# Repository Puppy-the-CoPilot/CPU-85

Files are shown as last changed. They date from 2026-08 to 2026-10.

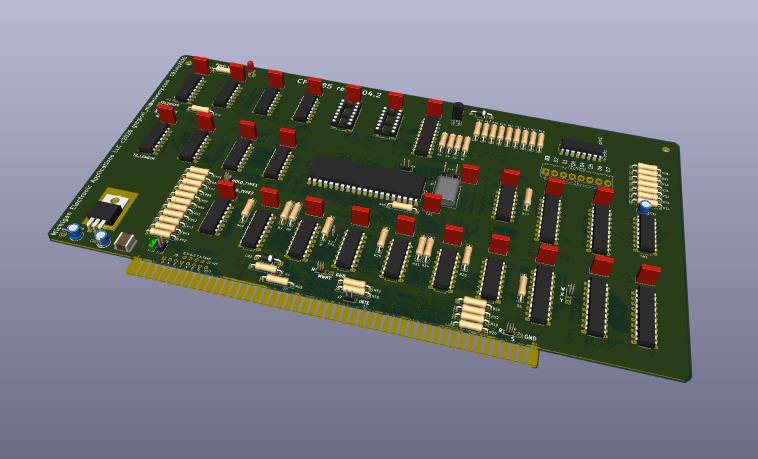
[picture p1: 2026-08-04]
CPU-85_R104_KiCAD_3D_View_21July2026.JPG

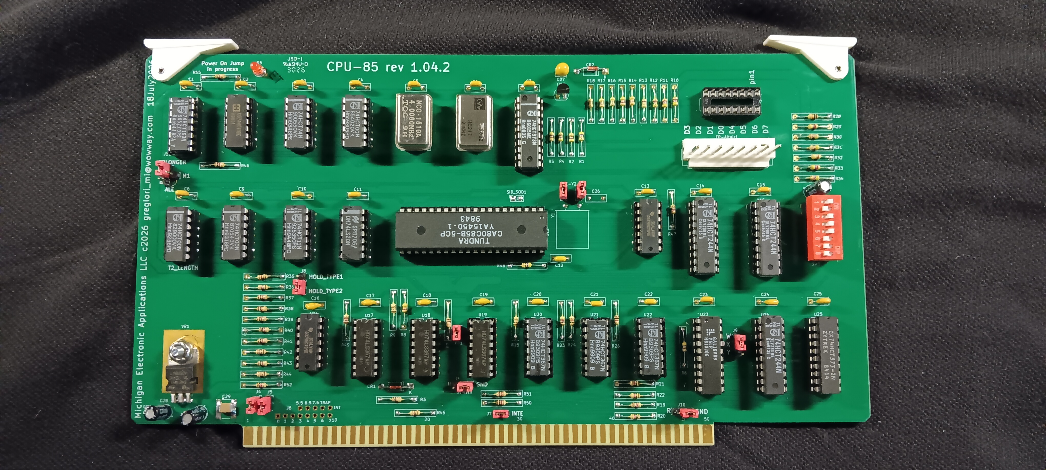
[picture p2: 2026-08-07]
photo_CPU85_front_6Aug2026_1000012285.jpg

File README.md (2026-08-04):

# CPU-85
8085 CPU based 1970s to 1980s era S-100 IEEE696 board outline card
last update: 28 July 2026

Purpose:
     * update MITS/Altair CPU-A board for modern EMC PCB layout principles
              ** have more Vcc and Ground to avoid switching niose risk
                    *** this helps prevent self induced switching noise (Conducted Immunity)
                    *** helps prevent Radiated Emissions in AM Band
              ** place decopupling capacitors next their respective ICs
     * improve CPU speed above 1975 limitations of the early 8080A as implemented by MITS/Altair/IMSAI
              ** HMOS 8085A upto 6MHz 
              ** CMOS 80C85A upto 5MHz, lower power
              ** CMOS CA80C85B upto 8MHz, B indicates a silicon die revision
     * add low voltage or 5Vcc < 4.7V forced RESET to help power up reliability
     * support IMSAI 8080A Front Panel and MITS/Altair 8800 Front Panel
              ** have 2 ribbon cable connectors
              ** S-100 jumpers and circuits for supporting signal varations
     * add Power On Jump to a user defined address (1K increments)
     * minimalist hardware, no IO, no RAM, no ROM, etc... just CPU
     * allow easy changing of CPU MHz speed 
              ** use DIP oscillator as flexible source
              ** have PCB holes to allow HC case quartz crystal
              ** allow use of 8 or 14 pin DIP oscillators
     * use jumper blocks to support IMSAI and MIS/Altair variations (they are not 100% the same)
     * maybe design a spin off varation to use the NSC800 (a Z80A hybrid with 8085 like pin out)
     * avoid using 8212 latch and 8216 bidirectional drivers (availability issues + old plastic encapsulation manufacturing)
  
Schematic: Completed 10 July 2026
           filename=CPU-85_schematic_21July2026.pdf
           (a living document, I will add more notes and validation results as those become available)

Software:  what ever the user had to run IMSAI 8080 or MITS/Altair 8800
           (this board lacks dedicated I/O so no special I/O drivers are needed)

PLD or PLA:  Yes there is 1, U23 is a GAL16V8 used as a CPU State Decoder
             filename=CPU-85_U23.jed

PCB Layout:  Gerbers Completed 17 July 2026
             filename=CPU-85_r104-F_Silkscreen.gbr

Bill Of Material:  Completed 18 July 2026
                   filename=CPU-85_rev1dot04_BOM_18July2026.xls

PCB Status: first blank check samples are being made in July 2026

First Validation Sample: In Progress as of 4 August 2026

Planned Validation:
     * test in IMSAI non Front Panel IMSAI PCS 80/30 
     * test in IMSAI 8080 system with IMSAI Front Panel 8080A
     * test in MITS/Altair 8800 system with MITS/Altair Front Panel

Errata:  None Known

contact email:  greglori_mi@wowway.com

Answers to Questions people asked:

Q:  8080A S-100 Boards had unique circuits for using their Front Panels
A:  I compared the schematics of IMSAI 8080A MPU-A, IMSAI 8085A MPU-B, and MITS/ALTAIR 8080 CPU-A.
    On IMSAI MPU-B, they just ran out of time and physical PCB space for the needed circuits... or just gave up on trying to achieve Front Panel compatibility.
    This board has different circuits to choose from in places where IMSAI, Intel, IEEE696, and MITS/Altair had some different circuits or logic.
    Most logic circuits were the same between IMSAI and MITS/Altair boards, but a few were differences... thus jumper blocks are used for circuit selections.
    So yes, there is some extra circuitry on this panel.
    See Page 12 of the schematic.  

Q: 8080A had a quirk or mirroring A0-A7 on A8-A15 during IO operations, does this panel do that?
A: Yes, the 8085A does this itself already.  Intel copied this characteristic from the 8080A to the 8085A.
   The OKI80C85A and CA80C85B specifications do not mention the IO address mirroring (they do state 100% pin and signal compatible).
   When A8-A15 are TriState, there are 5V pull ups to make FFH as a default for the Front Panel.

Q: One person wrote this panel uses 74HCTxx logic gates, they had mixed results using 74HCT family gates...
A: Lately I've been using 74HCT on my designs for lower power consumption.   
   For me, 74LS and 74HCT have been interchangeable for CPU speed <5MHz, I've had no bad experiences.
   Only difference I found was on 74HCT07 is clamped to Vcc or 5V, where as 74LS07 is true Open Collector with Vce=30V (no connection to Vcc)... 
   74HC07/74HCT07 and 7407/74LS07 are not interchangeable when pull up voltage is >5V.

Q. a person made a program to use 8085's RIM and SIM instructions...can SID and SOD be used?
A. Yes, SID and SOD are brought out from CPU to solder holes and pads. 

Q. Hard Gold on S-100 Edge Card fingers?
A. Yes, although Gold is now very expensive, 20u" (Industrial grade) is used for durabiliity vs. 30u" (Medical/Military grade)

Q. Hot Air Solder Pre Tin solder pads
A. No.  To prevent any surface oxidation before parts get soldered and to allow for a long shelft life, a thin 3u" gold coating has been applied

Q. NCS800 CPU version?
A. Probably not to be designed or made.  There is no interest, there are already Z80 CPU panels with IMSAI Front Panel ribbon connectors
   that go faster than the NSC800.  NCS800 offers no speed or any other improvement over the existing Z80 PCBs.  
   The NSC800 was not developed further as a product, only a 4MHz version appears to exist.

Q. M1 OpCode Fetch and other CPU State info on the S-100 Data Out Bus during PSYNC was missing...
A. Added as a result of an early July Vintage Computer Group schematic review (hence the July 10 reivsion);
   the CPU States are now latched and placed on the S-100 DO0-DO7 signals during the PSYNC Cycle.
   On the 8080A, the PSYNC cycle lasted 4 XTAL clock cycles, or 2T machine states; on this panel
   the user can select PSYNC to be 1 of 3 sources: sM1, ALE as used by IMSAI MPU-B (1T 8085A machine cycle), or a 
   lengthened 8080A like signal (2T cycles long).

Q. what is done with extended address A16 to A23?
A. just like 1975 and 1970 era CPU panels, the pre IEEE-696 S-100 pins for A16-A23 are left floating, no pull ups or pull downs on this panel;
   if the receiving S-100 system has bus card termination, they will be pulled up to about 2.3V to 2.5V or logic 1 by the signal line terminators;
   this panel can only address 64K bytes like the original 1970s era CPU panels

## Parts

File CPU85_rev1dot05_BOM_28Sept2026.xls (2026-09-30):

BILL OF MATERIALS |  | CPU-85 BOARD rev 1.04.2 and 1.05
original draft, 18 July 2026
6August2026 update
7August2026 update
11August2026, added column M and N cost estimates
16Aug2026, added note about avoiding 85C85A;, 80C85AH is OK
28Aug2025 U10 and U27 updates
28Sept2026 U1 changed, U23 file updated, C27 no longer needed
Reference Label(s) | Qty | Value | Data Sheet | Footprint |  | Est cost | Possible Purchase web pages |  | (these are examples, no one source has everything, I bought from different sites)
procedure info | AR | 24-7068-1401 Kester Sn 96.5% Ag 3% Cu 0.5% 0.020inch diameter No Clean Flux Solder (RoHS compliant, OK to send a finished board to Europe) ANSI-STD-006B or equivalent |  |  |  | $0.00 | you might already have this
procedure info | info | NOTE: I find small diameter solder is easier to apply. Too easy to melt and apply excessive solder with larger diameter solder. |  |  |  | NA
procedure info | alternative | 24-6337-9702 Kester Sn 60% Pb 40% 0.015inch diameter Flux Core Solder (not RoHS compliant, OK for USA only) ANSI-STD-004 or equivalent (from Mouser.com) |  |  |  | $0.00 | you might already have this
procedure info | optional | black vinyl electrical tape 3M, UtiliTech |  |  |  | $0.00 | you might already have this
procedure info | AR | Kwik Clean Flux Cleaner 16 Oz (available from Amazon), might need 2 bottles if rosin core solder is used |  |  |  | $0.00 | you might already have this
procedure info | info | Do not use >70% Isopropyl Alcohol = too harsh, it turns any surface contaminants to an adhesive like goo that is difficult to remove and the result looks terrible. |  |  |  | NA
procedure info | AR | ZEP Heavy Duty Citrus Degreaser (24oz squirt bottle) |  |  |  | $0.00 | you might already have this
procedure info | AR | Distilled Water for rinse off |  |  |  | $0.00 | I used tap water
J1, rev 1.04,2 | obsolete | blank CPU-85 PCB panel, 2 layer, FR4, IEEE696 size, 30U” hard gold edge connector |  | s100_panel:S-100-IEEE696_ejector_holes_3July2026 |  | NA | need to get 2 or 3 quotes, I don’t know cost yet, wide cost variation for quantity = 5, 25, 50
J1, rev 1.04,3 (with inner Vcc and Ground planes) | none made | blank CPU-85 PCB panel, 4 layer, FR4, IEEE696 size, 30U” hard gold edge connector |  | s100_panel:S-100-IEEE696_ejector_holes_3July2026 |  | NA
J1, rev 1.05 (has 1.04.2 silk screen corrections) | not yet made | blank CPU-85 PCB panel, 2 layer, FR4, IEEE696 size, 15U” hard gold edge connector |  | s100_panel:S-100-IEEE696_ejector_holes_3July2026 |  | NA
schematic | document | 1.04.2 and 1.05 CPU-85 schematic, instructions, user options, design info | CPU-85_schematic_17July2026.pdf will have newer text updates |  |  | NA
C1,C2,C3,C4,C5,C6,C7,C8,C9,C10,C11,C12,C13,C14,C15,C16,C17,C18,C19,C20,C21,C22,C23,C24,C25 | 25 | 100nf, 50V, dipped MLCC leaded, ceramic | K104M15X7RF5TL2 | Capacitor_THT:C_Rect_L7.2mm_W2.5mm_P5.00mm_FKS2_FKP2_MKS2_MKP2 |  | $10.00 | eBay purchase | https://www.ebay.com/itm/137189394879?_skw=100nf+50V+MLCC+radial&itmmeta=01KZRSP62M9DDHPF0N0Z78RN4S
C26 | optional | 20pf, 25V (use only with Y1 <4MHz) | K104M15X7RF5TL2 | Capacitor_THT:C_Rect_L7.2mm_W2.5mm_P5.00mm_FKS2_FKP2_MKS2_MKP2 |  | $0.00
C27 | not required | 10nF to 10uF 10V to 50V ceramic for low leakage, C27 not needed U27 provides >300mS reset time | CGA5L1X7R1C106K160AC | Capacitor_THT:C_Disc_D3.8mm_W2.6mm_P2.50mm |  | $0.79 | https://www.jameco.com/z/TM10-16-James-Electronics-10-uF-16-Volt-Tantalum-Capacitor_94060.html
C28,C30,C31 | 3 | 10uF 50V, radial electrolytic (25V minimum) |  | Capacitor_THT:CP_Radial_D5.0mm_P2.50mm |  | $0.45 | https://www.jameco.com/z/ECA-1HM100-JVP-Jameco-ValuePro-10-uF-50-Volt-Radial-Capacitor_29891.html
C29 | 1 | 10uf, 25V, 1812 size ceramic or SMC tantalum (to insure low ESR) | 2388-PCT47/16CK | Capacitor_SMD:C_2225_5664Metric_Pad1.80x6.60mm_HandSolder |  | $0.25 | almost any SMD 1210 to 1825 will fit on the pads. Mine was from a scrap Smd machine strip
CR1 | optional | 1N4148, or 1N914, with C27 deleted, this diode is no longer needed to discharge C27
CR2 | 1 | 1N4148, or 1N914, current is less than 50mA (small signal) | http://www.vishay.com/docs/88525/1n5817.pdf | Diode_THT:D_DO-41_SOD81_P10.16mm_Horizontal |  | $0.06 | https://www.jameco.com/z/1N4148-Fairchild-onsemi-Diode-1N4148-100V-200mA-10mA-If-Small-Signal-Switching-Bulk-_36038.html
D5 | 1 | T1 LED (shows when PCB is in POJ, any color is OK, I used a red LED) |  | LED_THT:LED_D3.0mm |  | $0.09 | https://www.jameco.com/z/L-354HD-MCD-Electronics-Red-LED-Diffused-3mm-T1-2-8V-695nm-2-5mcd_2329183.html
FP-Altair1 | option | Molex 26-60-4080 VERT 8POS 3.96MM (for MITS/Altair Front Panel) |  | Connector_Molex:Molex_KK-396_A-41791-0008_1x08_P3.96mm_Vertical | I can sell with PCB | $1.10 | eBay purchase | https://www.ebay.com/itm/134631814875
 |  | Implementation varaition1: use wire cutters, break off female retention clip and keep the white plastic connector base (no retaining feature is most common)(cracks off easily) |  |  |  | NA
 |  | Implementation varaition2: use pliers, pull out all pins from the white connector, no plastic connector base (just use the big pins) |  |  |  | NA
 |  | Implementation varaition3: solder wires to Front Panel directly into the PCB, don’t use a connector (not recommended) |  |  |  | NA
 |  | Implementation varaition4: use mating 10 pin female connector (2 cavities are empty, yes its too wide, 8 position female connector does exist) |  |  |  | NA
 |  | Implementation varaition5: solder it in, keep the female connector retaining clip |  |  |  | NA
 |  | NOTE: Due to connector height, CPU card must be on the end of mother panel or adjacent S-100 must have no card installed to allow for mating connector and wires) |  |  |  | NA
FP-IMSAI1 | option | 16pin DIP socket (to IMSAI Front Panel) |  | Package_DIP:DIP-16_W7.62mm_LongPads |  | $0.00 | https://www.jameco.com/z/1-2199298-4-TE-Connectivity-16-Position-Dual-Wipe-Ladder-Style-DIP-IC-Socket-0-3-Wide-0-1-Pitch_2246080.html
R1,R2,R4,R5,R6,R48 | 6 | 470, 5% tol, 1/6W used, 5% tol, 1/8W or 1/10W, 1977 original was 1/4W |  | s100_panel:R_Axial_DIN0309_L7.5mm_D2.7mm_P12.50mm_Horizontal |  | $0.09 | eBay purchase | https://www.ebay.com/itm/406736220263?_skw=1%2F8w+resistor&itmmeta=01KZRSD28YGP9NY7HF8VVWRQE5&var=676974156631
R3,R9,R14,R19,R20,R21,R22,R23,R24,R25,R26,R35,R36,R37,R39, R40,R41,R42,R43,R44,R45,R46,R47,R49,R50,R51,R52,R55 | 28 | 1K, 5% tol, 1/6W used, 5% tol, 1/8W or 1/10W, 1977 original was 1/4W |  | s100_panel:R_Axial_DIN0309_L7.5mm_D2.7mm_P12.50mm_Horizontal |  | $0.42 | eBay purchase | https://www.ebay.com/itm/406736220263?_skw=1%2F8w+resistor&itmmeta=01KZRSD28YGP9NY7HF8VVWRQE5&var=676974156631
R7,R28,R38 | 3 | 10K, 5% tol, 1/6W used, 5% tol, 1/8W or 1/10W, 1977 original was 1/4W |  | s100_panel:R_Axial_DIN0309_L7.5mm_D2.7mm_P12.50mm_Horizontal |  | $0.04 | eBay purchase | https://www.ebay.com/itm/406736220263?_skw=1%2F8w+resistor&itmmeta=01KZRSD28YGP9NY7HF8VVWRQE5&var=676974156631
R8,R10,R11,R12,R13,R15,R16,R17,R18,R29,R30,R31,R32,R33,R34 | 15 | 4.7K, 5% tol, 1/6W used, 5% tol, 1/8W or 1/10W, 1977 original was 1/4W |  | s100_panel:R_Axial_DIN0309_L7.5mm_D2.7mm_P12.50mm_Horizontal |  | $0.22 | eBay purchase | https://www.ebay.com/itm/406736220263?_skw=1%2F8w+resistor&itmmeta=01KZRSD28YGP9NY7HF8VVWRQE5&var=676974156631
no label | optional | 8pin DIP sockets, dual wipe, for 8 pin oscillators (remove or push out from the bottom pins 2,3,6,7 for Y2 and Y3 oscillators) |  |  |  | $0.00 | https://www.jameco.com/z/390261-2-TE-Connectivity-8-Position-Dual-Wipe-Ladder-Style-DIP-IC-Socket-0-3-Wide-0-1-Pitch_526299.html
no label | 11 | 14pin DIP sockets, dual wipe (on 2 sockets remove or push out from the bottom pins 2,3,5,6,9,10,12,13 for 8 and 14 pin Y2 and Y3 oscillators) |  |  |  | $2.42 | https://www.jameco.com/z/ICS-314-T-Jameco-ValuePro-Socket-IC-14-Pin-Dual-Wipe-Low-Profile-0-3-Inch-Wide_112214.html
no label | 9 | 16pin DIP sockets, dual wipe |  |  |  | $1.62 | https://www.jameco.com/z/ICS-316-T-Jameco-ValuePro-IC-Socket-16-Pin-Dual-Wipe-Low-Profile-0-3-Inch-Wide_112222.html
no label | 6 | 20pin DIP sockets, dual wipe |  |  |  | $1.14 | https://www.jameco.com/z/20LPD-Jameco-ValuePro-20-Pin-0-3-Inch-Wide-Low-Profile-Dual-Wipe-IC-Socket_112248.html
no label | 1 | 40pin DIP socket, dual wipe |  |  |  | $0.59 | https://www.jameco.com/z/ICS-640-T-Jameco-ValuePro-40-Pin-Dual-Wipe-Low-Profile-IC-Socket-0-60-Inch-Wide_112311.html
U1 | 1 | 74HCT161, 4 bit counter with asynchronous reset | http://www.ti.com/lit/gpn/sn74LS161 | Package_DIP:DIP-16_W7.62mm_LongPads |  | $1.05
U2 | 1 | 74HCT02 | http://www.ti.com/lit/gpn/sn74hct02 | Package_DIP:DIP-14_W7.62mm_LongPads |  | $2.75 | eBay purchase | https://www.ebay.com/itm/163652946861?_skw=74HCT02+DIP&itmmeta=01KZRV2DQ9684WWSCPAVSTCC3Z
U3 | 1 | 74HCT74 | https://assets.nexperia.com/documents/data-sheet/74HC_HCT74.pdf | Package_DIP:DIP-14_W7.62mm_LongPads |  | $0.69 | https://www.jameco.com/z/74HCT74-Major-Brands-IC-74HCT74-DUAL-D-TYPE-FLIP-FLOP_45137.html
U4,U8,U9 | 3 | 74HCT00 | http://www.ti.com/lit/gpn/sn74hct00 | Package_DIP:DIP-14_W7.62mm_LongPads |  | $2.67 | https://www.jameco.com/z/74HCT00-Major-Brands-IC-74HCT00-QUAD-2-INPUT-POSITIVE-NAND-GATE_44871.html?CID=MERCH
U7, U25 | 2 | 74HCT373 alternative is 74LS373 | http://www.ti.com/lit/gpn/sn74LS373 | Package_DIP:DIP-20_W7.62mm_LongPads |  | $0.90 | https://www.jameco.com/z/74HCT373-On-Semiconductor-IC-74HCT373-OCTAL-D-TYPE-FLIP-FLOP-TRANSPARENT-LATCH_45065.html
U10 | 1 | 74HCT10 |  | Package_DIP:DIP-14_W7.62mm_LongPads |  | $0.76 | eBay purchase | https://www.ebay.com/itm/122187236230?_skw=74hct11+dip&itmmeta=01KZRV61D3GTJTZV0JB4F3KXXV
U11 | 1 | 74HCT20 |  | Package_DIP:DIP-14_W7.62mm_LongPads |  | $0.76 | eBay purchase | https://www.ebay.com/itm/121345271895
U12 | 1 | 80C85B-8PC (8MHz); alternatives are 8085A -2 -1 (3,5,and 6MHz), 80C85AH (5MHz see warning), 80C85B-#PC (#=3,5,6,8MHz) |  | Package_DIP:DIP-40_W15.24mm_LongPads | I can sell with PCB | $9.00 | eBay purchase | https://www.ebay.com/itm/317536556880?_skw=80c85B&itmmeta=01KZRTVRER91H1E71EEHFWDXB4
U13,U16 | 2 | 74HCT04 | https://assets.nexperia.com/documents/data-sheet/74HC_HCT04.pdf | Package_DIP:DIP-14_W7.62mm_LongPads |  | $1.78 | https://www.jameco.com/z/74HCT04N-Major-Brands-IC-74HCT04-HEX-INVERTER_44898.html?CID=MERCH
U14,U15,U24 | 3 | 74HCT244, alternatives are 74LS244 and 74S244 | http://www.ti.com/lit/ds/symlink/sn74ls244.pdf | Package_DIP:DIP-20_W7.62mm_LongPads |  | $3.45 | https://www.jameco.com/z/74HCT244-Major-Brands-IC-74HCT244-Octal-3-State-Buffer_45022.html
U17,U18,U19,U20,U21,U22 | 6 | 74HCT367 alternatives are 74LS376 and 8T97 (test board has 3 HCT and 3 LS) | http://www.ti.com/lit/gpn/sn74LS367 | Package_DIP:DIP-16_W7.62mm_LongPads |  | $8.34 | https://www.jameco.com/z/74LS367-Major-Brands-IC-74LS367-Tri-State-Hex-Buffer_47562.html
U23 | 1 | GAL16V8D | https://www.bitsavers.org/components/latticeSemiconductor/_dataBooks/1988_Lattice_GAL_Data_Book.pdf | Package_DIP:DIP-20_W7.62mm_LongPads |  | $3.75 | https://www.jameco.com/z/GAL16V8D-15LP-Lattice-Semiconductor-IC-16V8D-15-High-Performance-EE-CMOS-PLD-Generic-Array-Logic-15ns-90mA-250MHz_2290551.html
CPU-85_U23rev3.jed | information | U23 programming file; Encrypt OFF, Lock Bit OFF on programmer |  |  |  | NA
U27 | 1 | DS1233D-5 VCC Monitor, an older DS1233A performed porly | DS1233D.pdf | Package_TO_SOT_THT:TO-92L_HandSolder |  | $2.49 | DigiKey
SW1 | 1 | SW_DIP 8 switches |  | Package_DIP:DIP-16_W7.62mm_LongPads |  | $1.09 | https://www.jameco.com/z/78B08-JVP-Jameco-ValuePro-8-Position-DIP-Switch-Standard-Raised-Slide-SPST-DIP-16_38842.html
FP1 | as required | 16 conductor ribbon cable (use for connecting to IMSAI type Front Panel or Control Panel) |  |  |  | NA | made this mayself
GND1 | optional | Test Clip loop or 1 pin vertical SIP header (I broke down a 40 pin strip to smaller bits) | https://www.digikey.com/en/products/detail/keystone-electronics/5271/12751683 |  |  | $0.00
FP,J4,J5,J7,USE-Y2_1,USE-Y2_2 | 7 | 2 pin vertical SIP header (I broke down a 40 pin strip to smaller bits) | Conn_02x01 | Connector_PinHeader_2.00mm:PinHeader_2x01_P2.00mm_Vertical,s100_panel:2pin_Jumper_block_P2.00mm_Vertical
J3,J8,J9,J10,J11 | 5 | 3 pin vertical SIP header (I broke down a 40 pin strip to smaller bits) | Conn_03x01 | s100_panel:3pin_Jumper_block_P2.00mm_Vertical |  | 0;.79 | https://www.jameco.com/z/PH1-40-UA-Adam-Technologies-40-Position-0-1-Straight-Single-Row-Pin-Header_2168211.html
side pin to make J11 a “T” shape | 1 | 1 pin vertical SIP header (I broke down a 40 pin strip to smaller bits) | Conn_01x01 |  |  | $0.00 | use from above
jumper blocks | 11 | 0..100” jumper blocks (any color) |  |  |  | $0.66 | https://www.jameco.com/z/2012J-OR-R-Jameco-ValuePro-0-100-2-54mm-Socket-Shortng-Blocks-Red-Open_112417.html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
VR1 | 1 | uA7805, LM340-5, 5V 1Amp regulator | http://www.ti.com/lit/ds/symlink/ua78.pdf | s100_panel:TO-220-3_Horizontal_Tab_Down_Ground_Plane |  | $0.49 | https://www.jameco.com/z/L7805CV-STMicroelectronics-IC-L7805CV-5V-1A-Positive-Voltage-Regulator-0-to-125C-Temp-_924633.html
to secure TO220 to PCB | 1 | 6-32 locking nut | Hillman brand name, check your local ACO or True Value hardware store |  |  | $0.25
to secure TO220 to PCB | 1 | 6-32 3/8 inch long screw | Hillman brand name, check your local ACO or True Value hardware store |  |  | $0.25
Heat Sink VR1 | optional | PCB Ground Plane provides sufficient heat sink area |  |  |  | $0.00
Y1 (if Y2 is not used) | optional | HC cased 455KHz to 12MHz quartz crystal |  |  |  | $0.00
Y2 | 1 | CXO_DIP14 (2MHz to 16MHz based on your system capability and CPU) | http://cdn-reichelt.de/documents/datenblatt/B400/OSZI.pdf | Oscillator:Oscillator_DIP-14 |  | $6.50 | eBay purchase | https://www.ebay.com/itm/365659168150?var=635442431841
Y3 | 1 | CXO_DIP14 (2MHz), IEEE-696 requirement | http://cdn-reichelt.de/documents/datenblatt/B400/OSZI.pdf |  | I can sell with PCB | $1.95 | https://www.jameco.com/z/MXO45-3C-2M0000-JVP-Jameco-ValuePro-2-MHz-Full-Can-TTL-Crystal-Oscillator_27924.html
WARNING: 80C85B 80C85AH are better than 80C85A variation, reference info OKI Technical Spec |  |  |  |  | total | $68.87

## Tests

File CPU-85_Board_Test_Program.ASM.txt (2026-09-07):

0000               0000 *************************************************************
0000               0010 *                                                           *
0000               0020 *   TEST PROGRAM FOR CPU-85 WITH 80C85B                     *
0000               0030 *                                                           *
0000               0040 *   SPECIFIC USE  : IMSAI PCS80/30 WITH CPU~85 PCB          *
0000               0050 *   UPDATE HISTORY: 8/10/2026 FIRST DRAFT                   *
0000               0060 *                   8/11/2026 FLOPPY CRASHED, SECOND DRAFT  *
0000               0066 *   WRITTEN       : BY GREG BOBE                            *
0000               0067 *                   GREGLORI_MI@WOWWAY.COM                  *
0000               0070 *                                                           *
0000               0080 *************************************************************
0000               0090                  LINK     'SYSNOV2025'
0000               0100 *************************************************************
0000               0110 *   PROGRAM INDEX TABLE                                     *
0000               0120 *************************************************************
0000      E000     0130 PROGSTART        EQU	0E000H		; COULD BE ANY WHERE
0000      019D     0140 BOOTLOADER~STACK EQU	0019DH          ; USE MICROPOLIS DOS STACK AREA
0000      F7E5     0150 BOOTLOADER~STACK~ALT EQU 0F7ES5H        ; USE VIDE0 RAM FOR STAK AREA
0000      0000     0160 RUNREMOTE~PROGRAM EQU 0000H             ; PLACE IN LOW MDOS STACK RANGE
0000               0170 *
0000               0180			 ORG      PROGSTART
E000               0190 *************************************************************
E000               0200 *   POWER ON RESET AND SUBROUTINE REMAPPING TABLE           *
E000               0210 *************************************************************
E000 C3 D7  El     0220 RESET           JMP      COLD~START
E003 C3 42  E2     0230 RAM~TEST~RETURN~POINT JMP RAM~TEST~COMPLETED
E006               0240 *
E006               0250 *************************************************************
E006               0260 *   TEXT STRINGS                                            *
E006               0270 *************************************************************
E006 21 5C E0      0280 NEXT~LINE	LXI 	H,CCRTL~MESS
E009 C3 B6 FF      0290                 JMP     IMSATF~VIOB~DISPLAY~STRING
E00C               0300 *
E00C 43 50 55      0310 GREETINGS~PROMPT DT     'CPU-85 BOARD TEST AND BOOTLOADER V.1 8/11/2026'
E00F 2D 38 35
E012 20 42 4F
E015 41 52 44
E018 20 54 45
E01B 53 54 20
E01E 41 4E 44
E021 20 42 4F
E024 4F 54 20
E027 4C 4F 41
E02A 44 45 52
E02D 20 56 2E
E030 31 20 38
E033 2F 31 31
E036 2F 32 30
E039 32 36
E03B 0D 0A 0A     0320			DB        0DH,0AH,0AH
E03E 20 20 20     0330 RAM~TEST~MESS    DTZ       '   47 BYTES OF RAM AVAILABLE '
E041 34 37 20
E044 42 59 54
E047 45 53 20
E04A 4F 46 20
E04D 52 41 4D
E050 20 41 56
E053 41 49 4C
E056 41 42 4C
E059 45 20 00
E05C 0D 0A 00     0340 CCRLF~MESS      DB        0DH,0AH,0
E0SF 4E 4F 20     0350 RAM~FAIL~MESS   DTZ       'NO MAIN PROGRAM OR DEFECTIVE MEMORY DETECTED AT 0000H"
E062 4D 41 49
E065 4E 20 50
E068 52 4F 47
E06B 52 41 4D
E06E 20 4F 52                                                                                                      .
E071 20 44 45
eO74 46 45 43
E077 54 49 56
E07A 45 20 4D
E07D 45 4D 4F
E080 52 59 20
E083 44 45 54
E086 45 43 54
E089 45 44 20
E08C 41 54 20
E08F 30 30 30
E092 30 48 00
E095 20 2E 2E     0360 NOT~ENOUGH~MESS DTZ     '  ...  NOT ENOUGH RAM, 20K MINIMUM REQIRED, CPU HALTED '
E098 2E 20 4E
E09B 4F 54 20                                                                                     .
E09E 45 4E 4F
E0A1 55 47 48
E0A4 20 52 41                                                                                                           :
E0A7 4D 2C 20
E0AA 32 30 4B
E0AD 20 4D 49
E0BO 4E 49 4D
E0B2 55 4D 20
E0B6 52 45 51
E0B9 55 49 52
E0BC 45 44 2C
E0BF 20 43 50
E0C2 55 20 48
E0C5 41 4C 54
E0C8 45 44 20
E0CB 00
E0CC 56 49 4F     0370 VIOB~MESS          DTZ       'VIOB EPROM CHECKSUM =  '
E0CF 42 20 45
E0D2 50 52 4F
E0D5 4D 20 43
E0D8 48 45 43
E0DB 4B 53 55
E0DE 4D 20 3D                                                           
E0E1 20 00
E0E3 46 4C 4F     0380 DISK~MESS          DTZ       'FLOPPY DISK ROM CHECKSUM = '
E0E6 50 50 59
E0E9 20 44 49
E0EC 53 4B 20
E0EF 52 4F 4D
E0F2 20 43 48
E0F5 45 43 4B
E0F8 53 55 4D
E0FB 20 3D 20
E0FE 00
E0FF 50 41 52     0390 PRINT~MESS        DTZ       'PARALLEL PRINTER PORT & KODAK 150 PLUS INITIALIZED '
E102 41 4C 4C
E105 45 4C 20
E108 50 52 49
E10B 4E 54 45
E10E 52 20 50                                                                                                      :
E111 4F 52 54
E114 20 26 20
E117 4B 4F 44
E11A 41 4B 20
E11D 31 35 30
E120 50 4C 55
E123 53 20 49
E126 4E 49 54
E129 49 41 4C
E12C 49 5A 45
E12F 44 20 00
E132 50 52 49     0400 PRINT~PTEST      DTZ       'PRINT A TEST PAGE’
E135 4E 54 20
E138 41 20 54
E13B 45 53 54
E13E 20 50 41
E141 47 45 00                                                                                     :
E144 4D 59 20     0410 PRINT~TEST~MESS  DT       'MY PUPPY IS A GOOD DOG’
E147 50 55 50
E14A 50 59 20
E14D 49 53 20
E150 41 20 47
E153 4F 4F 44
E156 20 44 4F
E159 47
E15A 0D 0A 80     0420                  DB        0DH,0AH,080H
E15D 2C 20 50     0430 RESULT~PASS      DTZ       ',  PASS’
E160 41 53  53
E163 00
E164 2C 20 46     0440 RESULT~FAIL      DTZ       ',  FAIL'
E167 41 49 4C
E16A 00
E16B 52  55 4E    0450 RUN~FROM~RAM~TEST DTZ      'RUN "NOP" PROGRAM FROM AVAILABLE MAIN RAM '
E16E 20 22  4E
E171 4F 50 22                             
E174 20 50 52
E177 4F 47 52                                                                
E17A 41 4D 20                                                          
EL7D 46 52 4F
E180 4D 20 41
E183 56 41 49
E186 4C 41 42
E189 4C 45 20
E18C 4D 41 49
E18F 4B 20 52
E192 41 4D 20
E195 00
E196 42 4F AF     0460 DISK~BOOT~MESS DTZ        'BOOTING FROM FLOPPY DISK 0 '
E199 54 49 4E
E19C 47 20 46
E19F 52 4F 4D
E1A2 20 46 4C
E1A5 4F 50 50
E1A8 59 20 44
E1AB 49 53 4B
E1AE 20 30 20
E1B1 00                                                                                           
EiB2              0470 *************************************************************
E1B2              0480 *  DELAYS
EiB2 21 87 00     0490 WAIT~1IMS        LXT      H,ONE"MILLISECOND  ; 1.004MS WITH 4MHZ 8085 CPU
E1B5 2B           0500 WATIT~1MS~LOOP   DCX      H
E1B6 7D           0510                  MOV      A,L
E1B7 B4           0520                  ORA      H
E1B8 C2 B5 B1     0530                  JNZ      WAIT~1MS~LOOP
E1BB C9           0540                  RET
EiBC CD C8 E1     0550 WAIT~5SECONDS    CALL     WAIT~1SECOND
EiBF CD C8 E1     0560                  CALL     WAIT~1SECOND
E1C2 CD C8 Ei     0570                  CALL     WAIT 1SECOND
E1C5 CD C8 E1     0580                  CALL     WAIT~1SECOND
EiC8 11 E8 03     0590 WAIT~1SECOND     LXT      D,1000D
E1CB CD B2 Ei     0600 WAIT~MS          CALL     WAIT~1MS                     .
E1CE 1B           0610                  DCX      D
E1CF 7A           0620                  MOV      A,D
E1D0 B3           0630                  ORA      E
EiD1 C2 CB E1     0640                  JNZ      WAIT~MS            ; LOOP AGAIN?
E1D4 C3 41 E3     0650                  JMP      DISPLAY~TIME~NOW   ; UPDATE HH:MM:SS ON SCREEN
E1D7              0660 *
EiD7              0670 *************************************************************
E1D7              0680 *   TEST HW AT SYSTEM RESET & BOOT DISK                     *
E1D7              0690 *************************************************************
E1D7 31 E5 F7     0700 COLD~START       LXT      SP,BOOTLOADER~STACK~ALT  ; SET STACK POINTER
E1DA F3           0710                  DI
E1DB              0720 *
E1DB              0730 *                            
E1DB              0740 * PERFORM HARDWARE HEALTH CHECKS THEN BOOT FROM DISK
E1DB              0750 *
E1DB              0760 *
EiDB CD 00 F8     0770                  CALL     IMSAI~VIOB~INIT~24X80  ; ERASE VIDE0 8CREEN
EiDE 21 0C E0     0780                  LXT      H,GREETINGS~PROMPT     ; PRESENT GREETING MESSAGE
E1E1 CD B6 FF     0790                  CALL     IMSAI~VIOB~DISPLAY~STRING
E1E4 CD 41 E3     0800                  CALL     DISPLAY~TIME~NOW
E1E7              0810 *
E1E7              0820 * MOVE RAM TEST PROGRAM TO REMOTE RAM ADDRESS
E1E7              0830 *
E1E7 0E 2F        0840                  MVI      C, RAMTTEST~CODE~LENGTH
E1E9 21 13 E2     0850                  LXI      H, RAMTTEST~START      ; POINT AT TEMPLATE OUTINE
E1EC 11 00 00     0860                  LXI      D, RUN"REMOTE~FROGRAM
E1EF              0870 * TRANSFER THE TEMPLATE PROGRAM TO REMOTE LOCATED RAM
E1EF 7E           0880 TRANSFER~PROGRAM~LOOP MOV A,M            ;  MOVE (HL) TO (DE)
E1F0 12           0890                  STAX     D
E1F1 23           0900                  INX      H                      ; NEXT LOCATION
E1F2 13           0910                  INX      D
E1F3 0D           0920                  DCR      C                      ; DONE YET?
E1F4 C2 EF El     0930                  JNZ      TRANSFER~PROGRAM~LOOP  ; DONE WHEN C=0
E1F7              0940 * WAS RAM TEST LOADED INTO RAM SUCCESSFULY?
E1F7 21 0C 00     0950                  LXT      H,0
ELFA 01 2F 00     0960                  LXI      B, RAM~TEST~CODE~LENGTH
E1FD CD CC E2     0970                  CALL     PROCESS~CHECKSUM  ; CHECK TEST PROGAM
E200              0980 *  CALL DISPLAY~CHECKSUM  ;  USE TO LEARN THE RAM CHECKSUM
E200              0990 *  HLT
E200              1000 *                                                                      .
E200 7A           1010                   MOV      A,D                  ; IS RAM PROGRAM CHECKSUM OK?00
E201 FE 11        1020                   CPI      011H
E203 C2 0C E2     1030                   JNZ      NO~RAM~FOUND
E206 7B           1040                   MOV      A,E
E207 FE 17        1050                   CPI      017H
E209 CA 00 00     1060                   JZ       RUN~REMOTE~PROGRAM  ; OK TEST RAM
E20C 21 SF E0     1070 NO~RAM~FOUND      LXI      H,RAM~FAIL~MESS
E20F CD B6 FF     1080                   CALL     IMSAI~VIOB~DISPLAY~ STRING
E212 76           1090                   HLT
E213              1100 *
E213              1110 *
E213              1120 * SPECIAL SOFTWARE THAT GETS RELOCATED BY THE HARDWARE TEST PROGAM
E213              1130 *
E213              1140 *
E213              1150 * TEST RAM FROM A REMOTE RAM ADDRESS SEPARATE FROM MAIN RAM
E213 21 2E 00     1160 RAM~TEST~START    LXI      H,RAMTTEST~CODE~LENGTH-1  ; START CHECKING
E216 01 3A 30     1170                   LXI      B,0303AH              ;  SAVE TIME WITH VALUES IN REG.BC
E219     1DED     1180 RELOCATION~OFFSET EQU RUN~REMOTE~PROGRAM-RAM~TEST~START
E219 7E           1190 RAM~TEST~LOOP     MOV      A,M
E21A 2F           1200                   CMA                            ; INVERT THEMEMORY VALUE
E21B 77           1210                   MOV      M,A                   ; STORE TEST VALUE
E21C BE           1220                   CMP      M                     ; WAS VALUE SUCCESS FULL SAVED?
E21D C2 2B 00     1230                   JNZ      BAD~RAM~FOUND+RELOCATION~OFFSET
E220 2F           1240                   CMA                            ; INVERT VALUE TO ORIGINAL VALUE                                                                                                              ;
E221 77           1250                   MOV      M,A                   ; RESTORE TEST VALUE
E222 BE           1260                   CMP      M                     ; WAS VALUE RESTORED?
E223 C2 2B 00     1270                   JNZ      BAD~RAM~FOUND+RELOCATION~OFFSET
E226 23           1280                   INX      H                     ; CHECK NEXT MEMORY LOCATION
E227              1290 *
E227 11 A4 F0     1300                   LXI      D,2*80+IMSAI~VIOB~RAM+4  ; DISPLAYED RAM COUNTER
E22A 1A           1310 COUNT~GOOD~RAM    LDAX     D                     ; INCREASE COUNTER DIGIT
E22B B0           1320                   ORA      B                     ; APPLY ASCII MASK IF NEW DIGIT
E22C 3C           1330                   INR      A                     ; INCREASE BY 1 AND SAVE IT
E22D 12           1340                   STAX     D                     ; CHECK FOR DIGIT ROLLOVER
E22E B9           1350                   CMP      C                     ; RIPPLE UP TO NEXT DIGIT IF 3AH
E22F C2 25 00     1360                   JNZ      RAM~COUNTER~DONE+RELOCATION~OFFSET
E232 78           1370                   MOV      A,B                   ; RESET THAT DIGIT
E233 12           1380                   STAX     D
E234 1B           1390                   DCX      D                     ; INCREASE THE NEXT DIGIT UP   
E235 C3 17 00     1400                   JMP      COUNT~GOOD~RAM+RELOCATION~OFFSET
E238 7C           1410 RAM~COUNTER~DONE  MOV      A,H                   ; END WHEN HL=0E000H
E239 FE E0        1420                   CPI      0E0H                  ; START FOR FLOPPY DISKROM IS MAXIMUM
E23B C2 06 00     1430                   JNZ      RAM~TEST~LOOP+RELOCATION~OFFSET
E23E C3 03 E0     1440 BAD~RAM~FOUND     JMP      RAM~TEST~RETURN~POINT ; TEST COMPLETE
E241 76           1450 RAM~TEST~END      HLT
E242       002F   1460 RAM~TEST~CODE~LENGTH EQU RAM~TEST~END~RAM~TEST~START+1
E242 CD 06 E0     1470 RAM~TEST~COMPLETED CALL    NEXT~LINE
E245 3A A0 F0     1480                   LDA      80D*2+IMSAI~VIOB~RAM  ; IS MSD >20K RAM
E248 C6 CF        1490                   ADT     -'1'                   ; IS IT GREATER THAN 20, THEN OK
E24A DA 54 E2     1500                   JC      VIOB~CHK~SUM           ; OK PROCEED TO NEXT TEST
E24D 21 95 E0     1510                   LXI     H,NOT~ENOUGH~MESS      ; NOT ENOUGH RAM BPCE, STOP CPU
E250 CD B6 FF     1520                   CALL    IMSAI~VIOR~DISPLAY~STRING
E253 76           1530                   HLT                            ; STOP GO NO FURTHER
E254              1540 *
E254              1550 *
E254              1560 * CHECK SUM TEST ON VIOB EPROM
E254              1570 *
E254		  1580 *
E254 21 CC E0     1590 VIOB~CHK~SUM       LXI     H,VIOB~MESS
E257 CD B6 FF     1600                    CALL    IMSAI"VIOB~DISPLAY~STRING
E25A 01 00 08     1610                    LXI     B,0B00H               ; LENGTH 2K BYTES                                                                                                    .
E25D 21 00 F8     1620                    LXI     H,IMSAI~VIOB~ROM      ; STARTING ADDRESS
E260 CD CC E2     1630                    CALL    PROCESS~CHECKSUM
E263 CD DE E2     1640                    CALL    DISPLAY~CHECKSUM
E266 01 2A 40     1650                    LXI     B,-0BFD6H             ; EXPECTED VIOB ROM CHECK SUM
E269 CD 0A E3     1660                    CALL    GRADE~CHECKSUM
E26C              1670 *
E26C              1680 *
E26C              1690 * CHECK SUM TEST ON DISK BOOT ROM
E26C              1700 *
E26C              1710 *
E26C 21 E3 E0     1720 DISK~CHK~SUM      LXI     H,DISK MESS
E26F CD B6 FF     1730                   CALL    IMSAI~VIOB~DISPLAY~STRING
E272 21 00 EC     1740                   LXI     H,MICROPOLIS~BOOT~FROM~DISK ; STARTING ADDRESS
E275 01 00 01     1750                   LXI     B,0100H               ; LENGTH 256 BYTES
E278 CD CC E2     1760                   CALL    PROCESS~CHECKSUM
E278 CD DE B2     1770                   CALL    DISPLAY~CHECKSUM
E27E 01 44 A4     1780                   LXI     B,-0SBBCH             ; EXPECTED DISK CARD ROM CHECK SUM
E281 CD OA E3     1790                   CALL    GRADE~CHECKSUM
E284              1800 *
E284              1810 *                
E284              1820 * EXERCISE PRINTER PORT CARD
E284              1830 *
E284              1840 *
E284 31 9D 01     1850 SETUP~PRINTER     LXI     SP,BOOTLOADER~STACK
E287 CD BB E3     1860                   CALL    LDINIT
E28A 21 FF B0     1870                   LXI     H,PRINT~MESS
E28D CD B6 FF     1880                   CALL    IMSAI~VIOB~DISPLAY~STRING
E200 CD BC E1     1890                   CALL    WAIT~5SECONDS
E203              1900 *   LXI H,TEST~PRINT  ;  PRINT A TEST PAGE
E203 21 44 E9     1910                   LXI     H,PRINT~TEST~MESS
E206 CD DB E3     1920                   CALL    PRINTLINEOUT          ; SEND OUT THAT PRINTER COMMAND
E209 CD BC E1     1030                   CALL    WAIT~SSECONDS
E29C CD 06 E0     1940                   CALL    NEXT~LINE
E20F              1950 *
E20F              1960 *
E20F              1970 * RUN A PROGRAM OF 56K NO OPERATIONS
E20F              1980 *
E20F              1990 *
E20F 21 6B E1     2000                   LXI     H,RUN~FROM~RAM~TEST
E2A2 CD B6 FF     2010                   CALL    IMSAT~VIOB~DISPLAY~STRING
E2A5 21 FF DF     2020                   LXI     H,PROGSTART-1
E2A8 11 BC E2     2030                   LXI     D,COMEBACK~HERE
E2AB 72           2040                   MOV      M,D
E2AC 2B           2050                   DCX      H
E2AD 73           2060                   MOV      M,E
E2AE 2B           2070                   DCX      H
E2AF 36 C3        2080                   MVI      M,OC3H             ; THE JUMPERINSTRUCTION
E2B1 2B           2090 CLEAR~RAM~LOOP    DCX      H                  ; POINT AT ADDRESS TO CEAR
E2B2 36 00        2100                   MVI      M,0
E2B4 7C           2110                   MOV      A,H                ; IS LOOP IN HL=0?
E2B5 BS           2120                   ORA      L
E2B6 C2 Bl E2     2130                   JNZ      CLEAR~RAM~LOOP
E2B9 C3 00 00     2140                   JMP      0000H              ; START AT THE BOTTOM OF RAM
E2BC 00           2150 COMEBACK~HERE     NOP
E2BD CD 06 E0     2160                   CALL     NEXTTLINE
E2C0              2170 *
E2C0              2180 *
E2C0              2190 *  TEST THE ABILITY TO BOOT FROM DISK ©
E2C0              2200 *
E2C0              2210 *
E2C0 21 96 E1     2220                   LXI      H, DISK~BOOT~MESS
E2C3 CD B6 FF     2230                   CALL     IMSAI~VIOB~DISPLAY STRING
E2C6 CD 06 E0     2240                   CALL     NEXT~LINE
E2C9 C3 00 EC     2250                   JMP      MICROPOLIS~BOOT~FROM~DISK  ; START FLOPY OPERATION  
E2CC              2260 *
E2CC              2270 *
E2CC              2280 * CHECKSUM CALCULATION AND DISPLAY SUBROUTINES
E2CC              2290 *
E2CC              2300 *
E2CC 11 00 00     2310 PROCESS~CHECKSUM  LXI      D,0               ; RESET SUMMED VALUE
E2CF 7B           2320 CHECKSUM~LOOP     MOV      A.M               ; GET MEMORY VALUE
E2D0 83           2330                   ADD      B                 ; EXISTING SUMMATION IN DE
E2D1 SF           2340                   MOV      E,A
E2D2 D2 D6 E2     2350                   JNC      NO~CHECKSUM~RIPPLE
E2D5 14           2360                   INR      D
E2D6 OB           2370 NOTCHECKSUM~RIPPLE DCX     B
E2D7 23           2380                   INX      H                 ; POINT AT NEXT ROM LOCATION
E2D8 78           2390                   MOV      A,B               ; IS LOOP IN BC=07
E2D9 B1           2400                   ORA      C
E2DA C2 CF E2     2410                   JNZ      CHECKSUM~LOOP     ; NOPE, KEEP SUMMING
E2DD C9           2420                   RET
E2DE              2430 *
E2DE 7A           2440 DISPLAYTCHECKSUM  MOV      A,D
E2DF CD 9A FF     2450                   CALL     IMSAI~VIOB~HEX~OUT
E2E2 7B           2460                   MOV      A,E
E2E3 C3 9A FF     2470                   JUMP     IMSAI~VIOB~HEX~OUT
E30A              2720 *
E30A 7B           2730 GRADE~CHECKSUM    MOV      A,E               ; ADD RESULT MUST BE 0000H
E30B 81           2740                   ADD      C
E30C C2 iE E3     2750                   JNZ      CHECKSUM~FAIL     ; IF NOT 0CH, THEN IT FAILED
E30F D2 13 E3     2760                   JNC      NO~GRADE~RIPPLE
E312 04           2770                   INR      B
E313 7A           2780 NO~GRADE~RIPPE    MOV      A,D
E314 80           2790                   ADD      B                 ; SUM OF HIGH BYTE MUST BE OOH TO PASS
E315 C2 1E E3     2800                   JNZ      CHECKSUM~FAIL
E318              2810 *
E318 21 5D Bil    2820 CHECKSUM~PASS     LXI      H,RESULT PASS
E31B C3 21 E3     2830                   JMP      COMMON~PF
E31E 21 64 E1     2840 CHECKSUM~FAIL     LXI      H,RESULT"FAIL
E321 CD B6 FF     2850 COMMON"PF         CALL     IMSAI~VIOB~DISPLAY~STRING
E324 CD 06 E0     2860                   CALL     NEXT LINE
E327 C3 41 E3     2870                   JMP      DISPLAY~TIME~NOW
E32A              2880 *
E32A              2890 *************************************************************
E32A              2000 *                                                           *
E32A              2010 *   UPDATE VIDE0 DISPLAY WITH HOURS,  MINUTE,  SECONDS      *
E324              2020 *                                                           *
E32A              2030 *   PURPOSE       :  TO SHOW TIME WHEN IN DOS & BASIC       *
E324              2940 *   SPECIFIC USE  :  IMSAI PCS  80/30                       *                                                                                              .
E32A              2050 *   LAST UPDATE   :    8/24/2020                            *
E32A              2960 *                                                           *
E32A              2970 *************************************************************
E324              2080 *
B32A              2990 *************************************************************
E32A              3000 *   SHOW TIME*
E32A              3010 *************************************************************
E32A 00           3020 DISPLAY~TIME~PACED NOP
E32B    E324      3030 SHOWTIME          EQU      DISPLAY~ TIME PACED
E32B F5           3040                            PUSH     PSW
E32C C5           3050                            PUSH     B
E32D 3A 7A 07     3060                            LDA      0778H    ; GET LAST TTME STAMP VALUE
E330 47           3070                            MOV      B,A      ; PUT IT IN B FOR NOW
E331 3E 20        3080                            MVI      A,020H   ; READ LOWER SECONDS RTC VALUE
E333 D3 FE        3000                            OUT      QT~RTIC~ADDR~PORT
E335 00           3100                            NOP               ; SMALL DELAY FOR SLOW RTC IC
E336 DB FD        3110                            IN       QT~RTC~DATA~PORT ; READ THE COUNTER
E338              3120  * ANI  OFH  ;  MASK OFF AND KEEP LOWER BITS
E338 B8           3130                            CMP      B        ; STILL THE SAME VALUE?
E339 CA 6F E3     3140                            JZ       DISPLAY~RTC~EXIT
E33C 32 7A 07     3150                            STA      077AH    ; SAVE FOR UPDATE COMPARING
E33F C1           3160                            POP      B
E340 F1           3170                            POP      PSW
E341              3180 *
E341 F5           3190 DISPLAY~TIME               PUSH     PSW
E342      E341    3200 DISPLAY~TIME~NOW EQU   DISPLAY~TIME
E342 C5           3210                            PUSH     B
E343 E5           3220                            PUSH     H
E344 D5           3230                            PUSH     D
E345 21 48 FO     3240                            LXI      H,QT~RTC~VIDEO~TIME~ADDR~24X80  ; DISPLAY TO VIDE0
E348              3250 * CONVERT HOURS REGISTERS
E348 3E 05        3260                            MVI      A,05
E34A 11 0F 03     3270                            LXI      D,O030FH ; REGISTER MASK
E34D CD 75 E3     3280                            CALL     DISPLAY~RIC~PAIR ; SHOW HOURS
E350              3200 *
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

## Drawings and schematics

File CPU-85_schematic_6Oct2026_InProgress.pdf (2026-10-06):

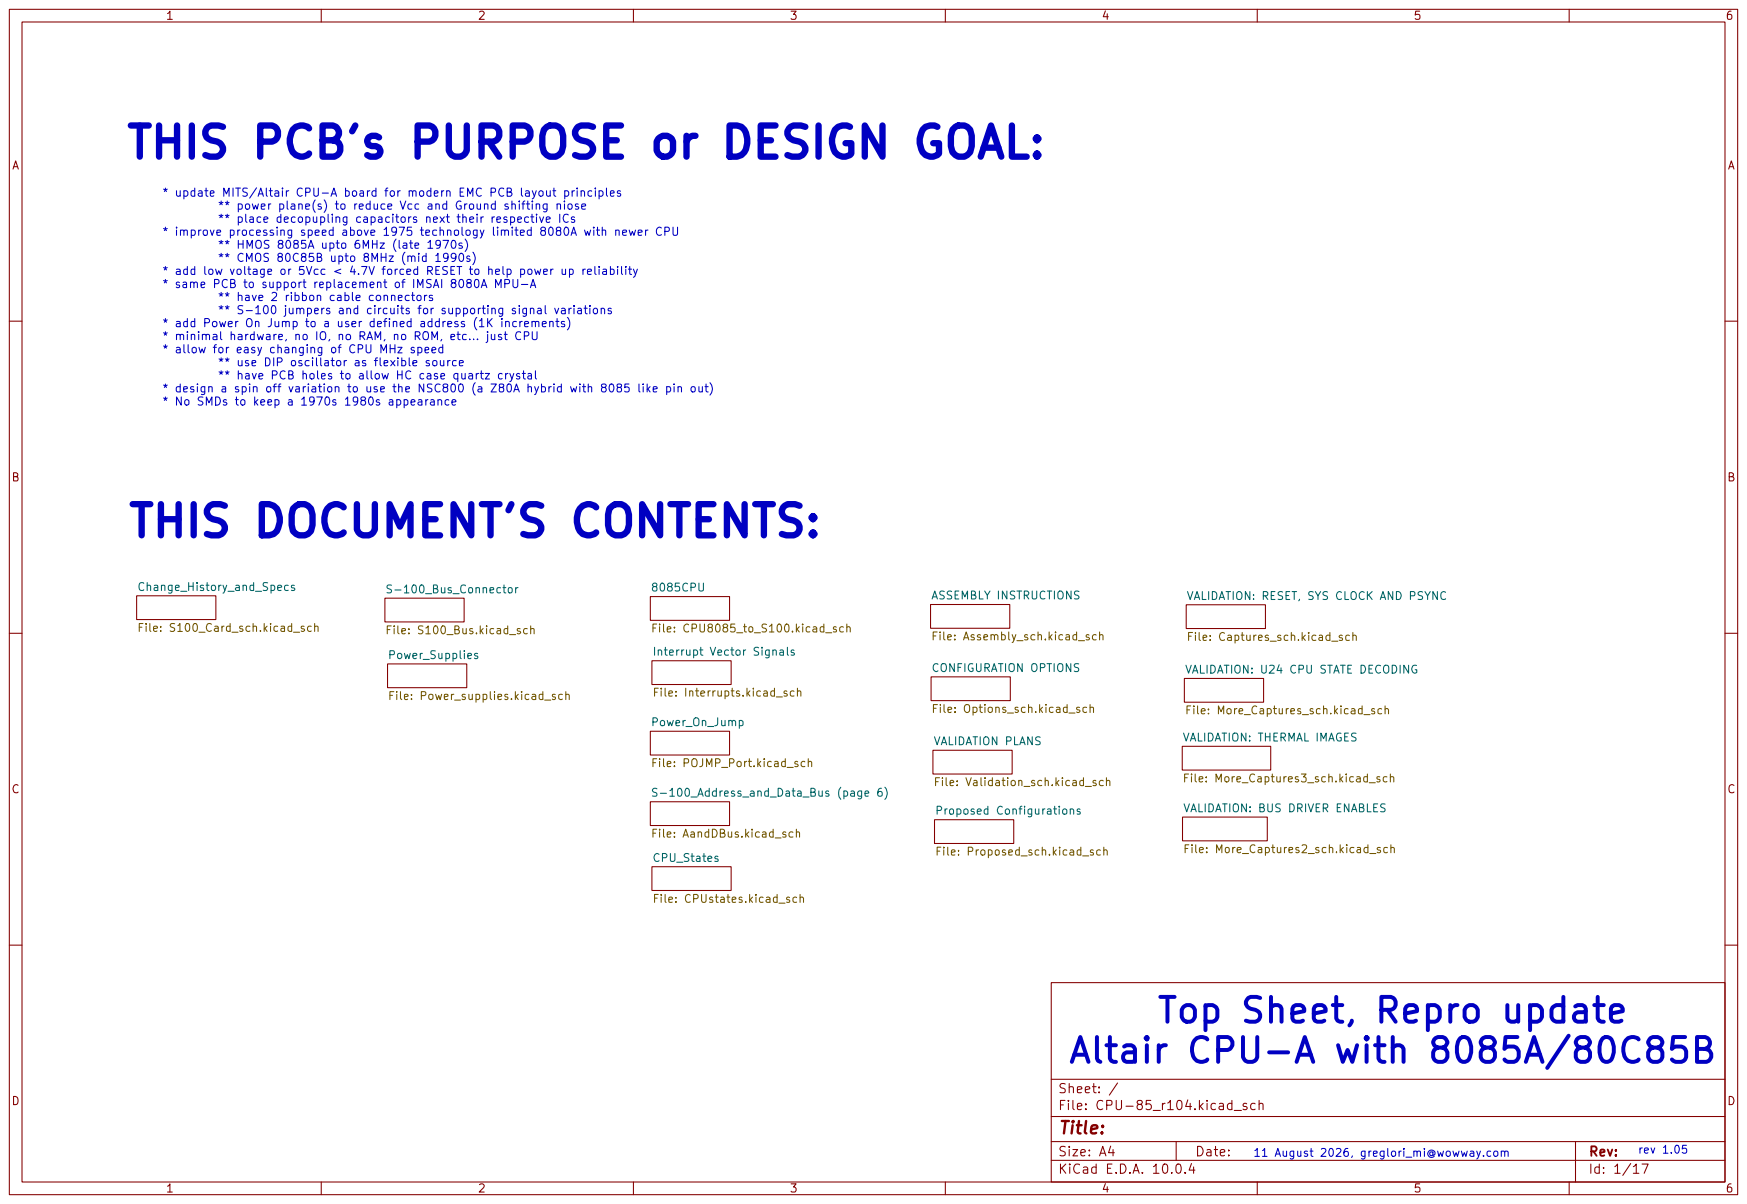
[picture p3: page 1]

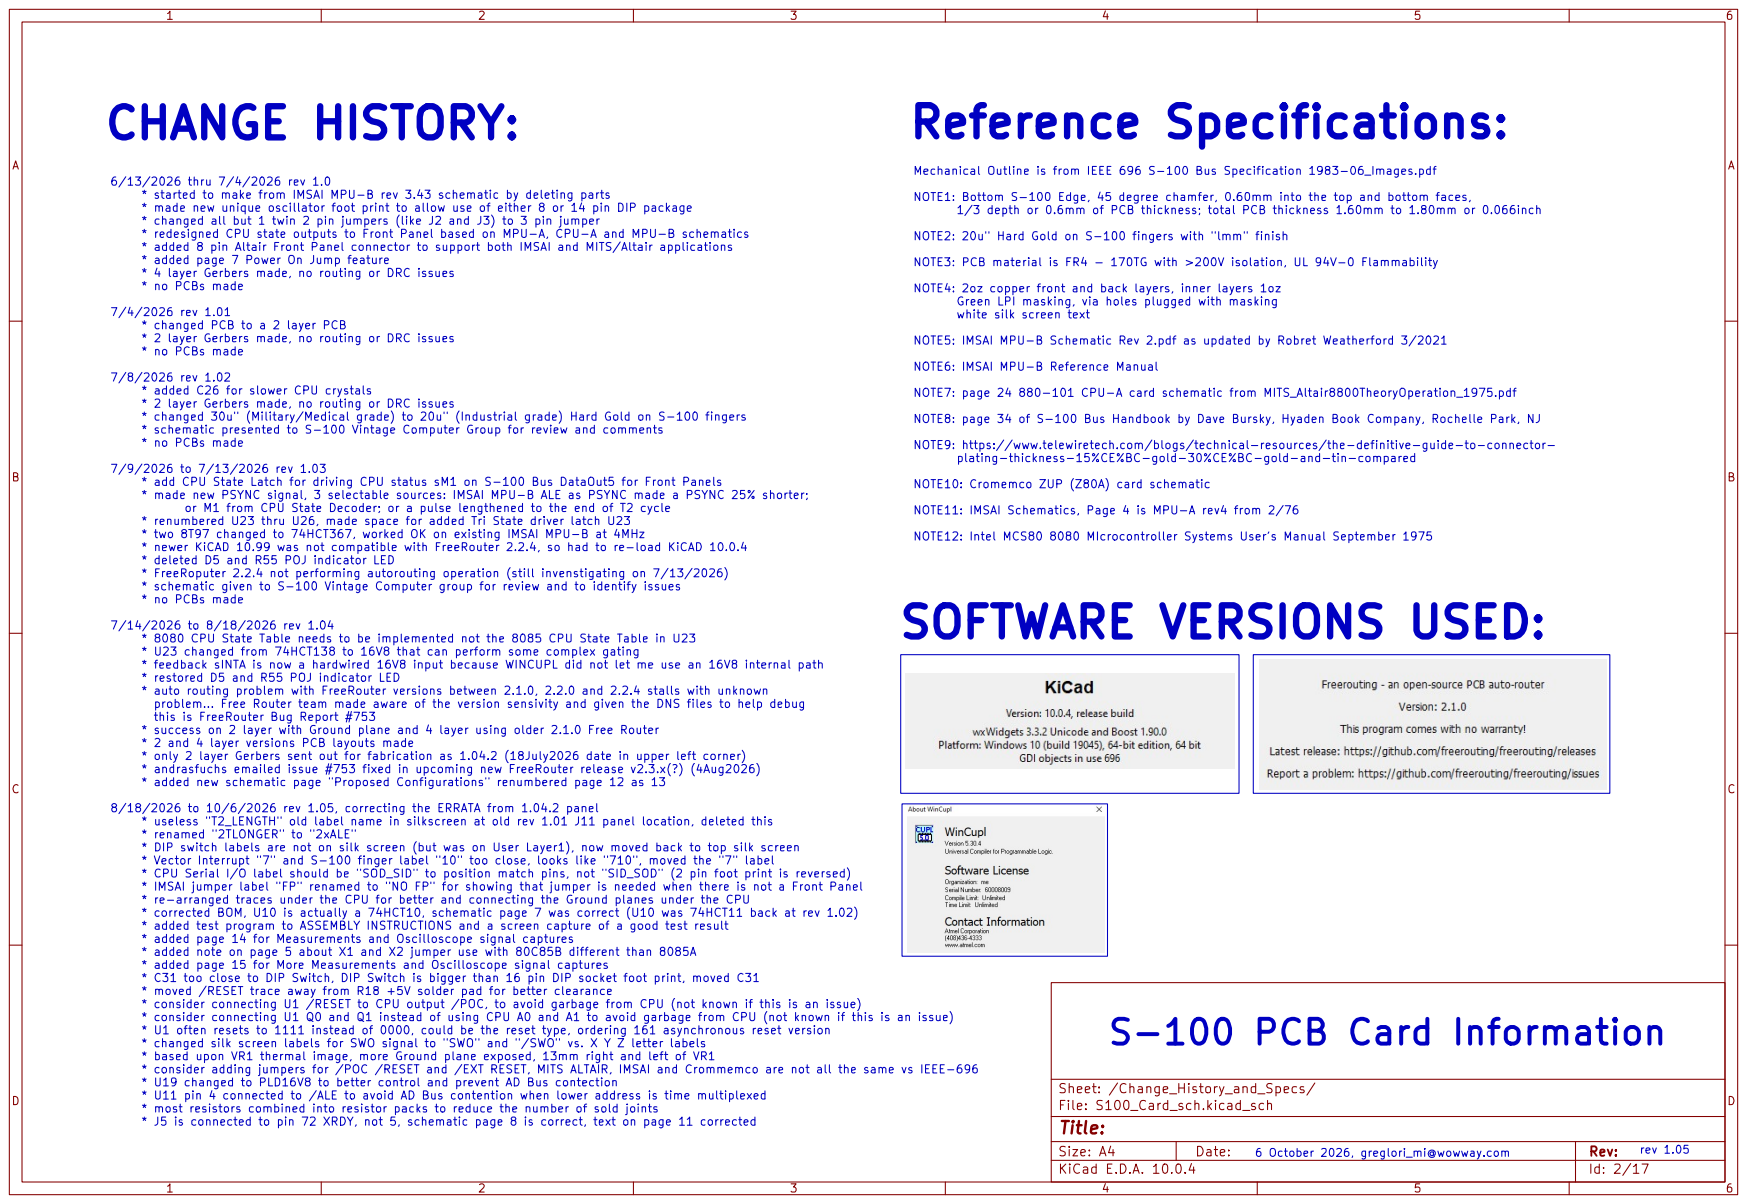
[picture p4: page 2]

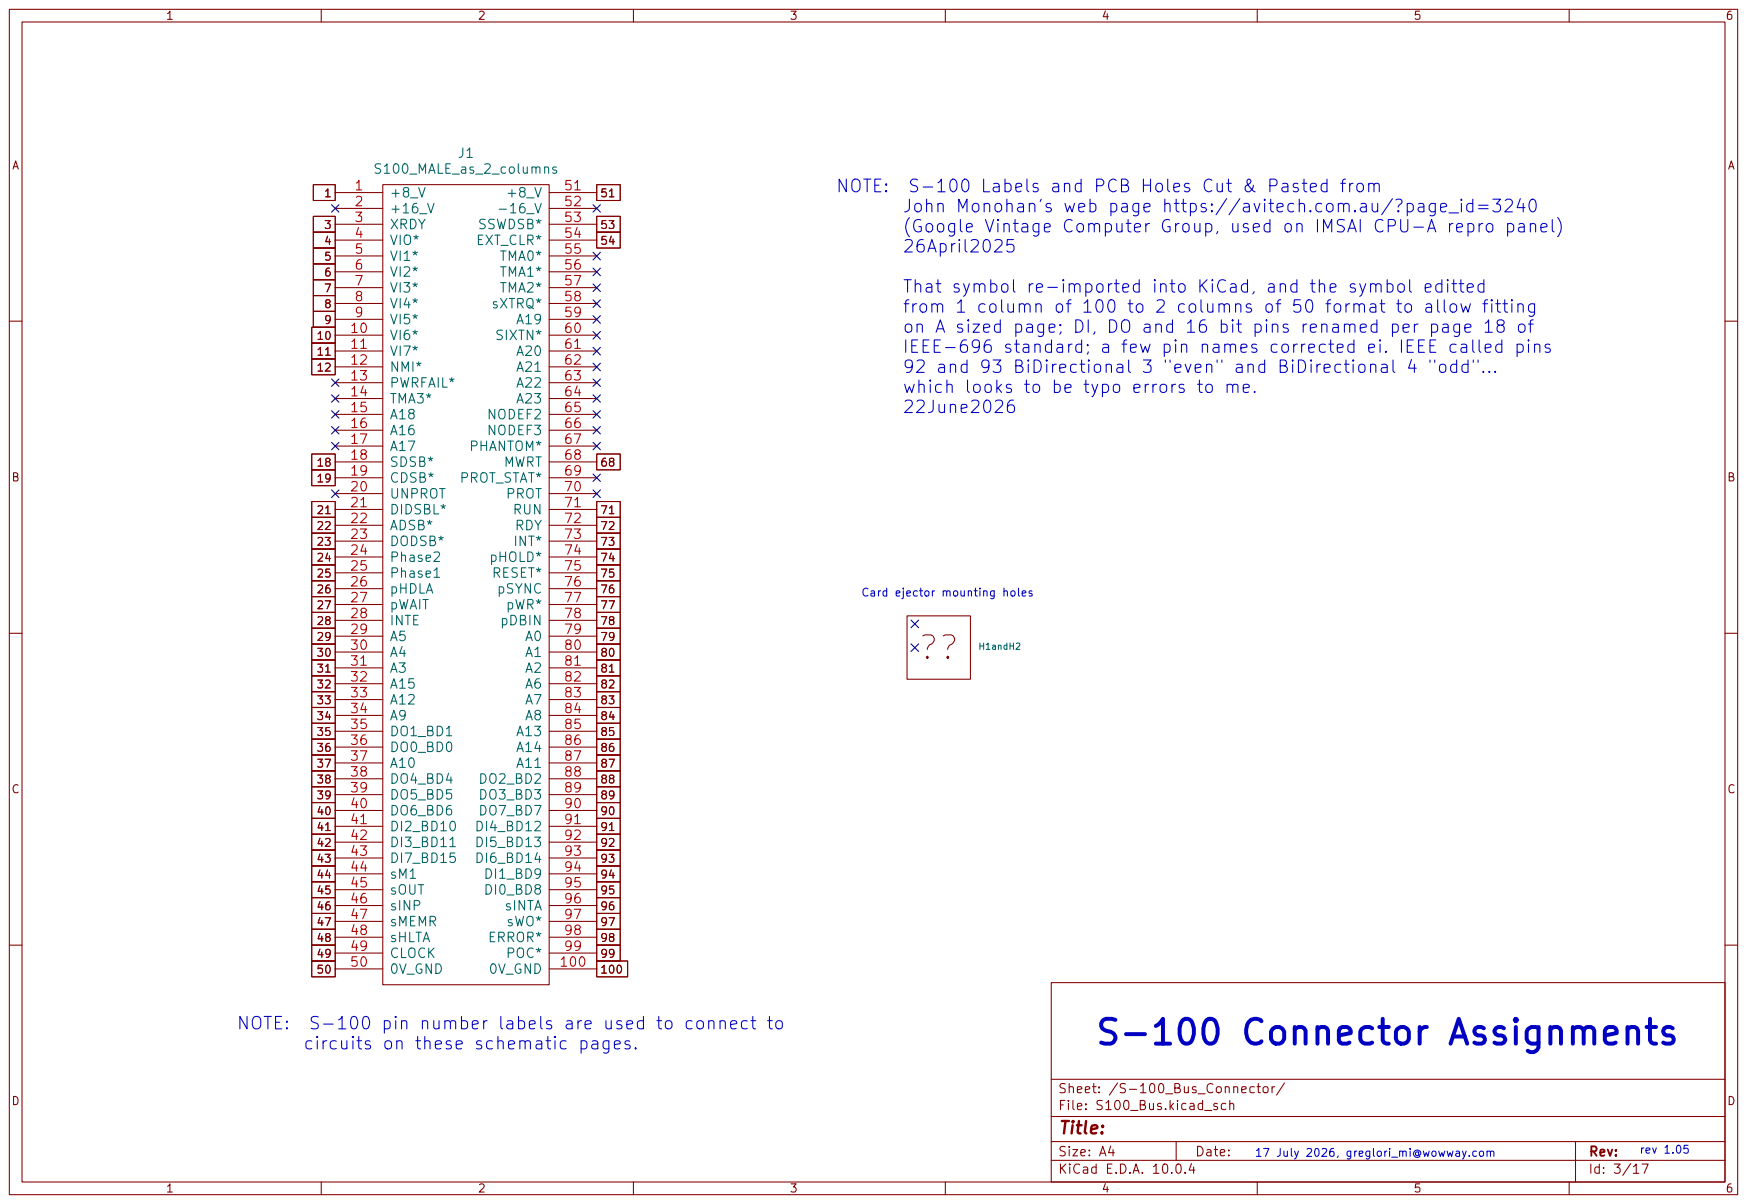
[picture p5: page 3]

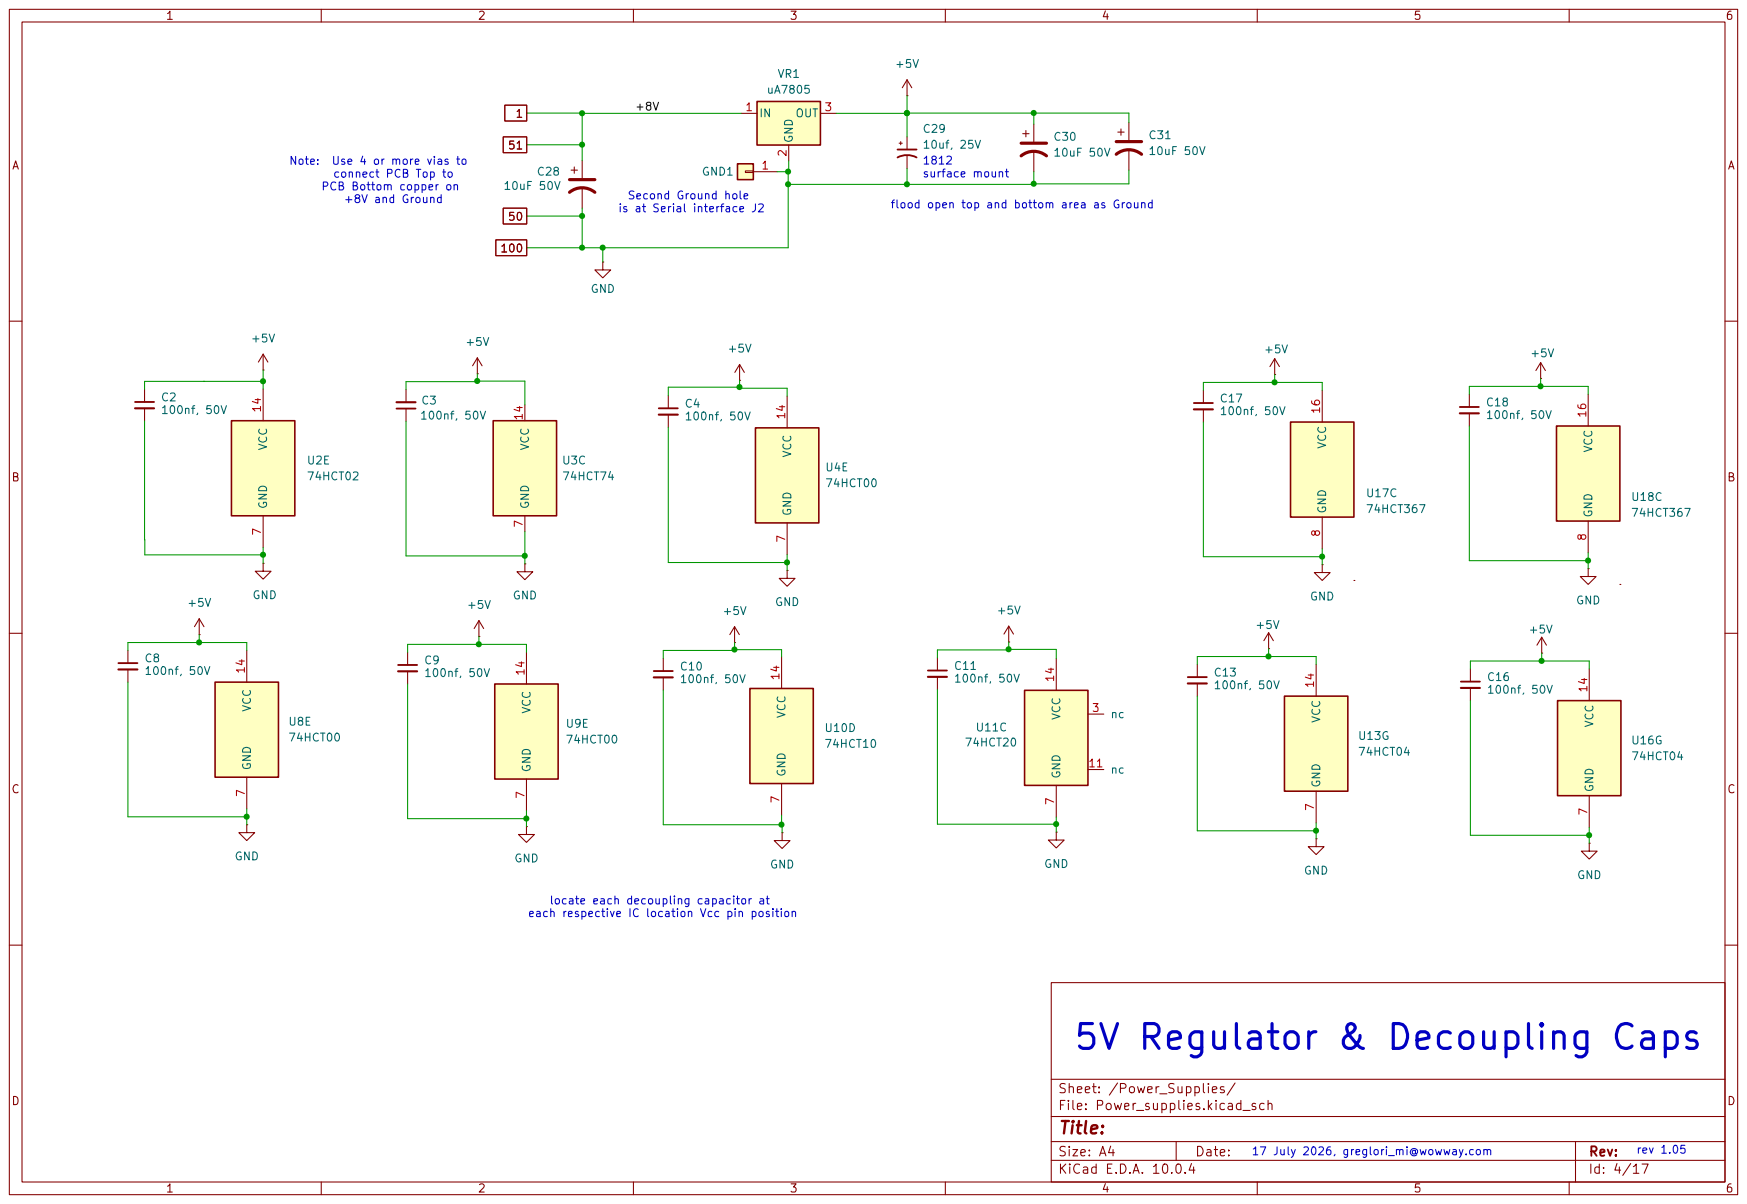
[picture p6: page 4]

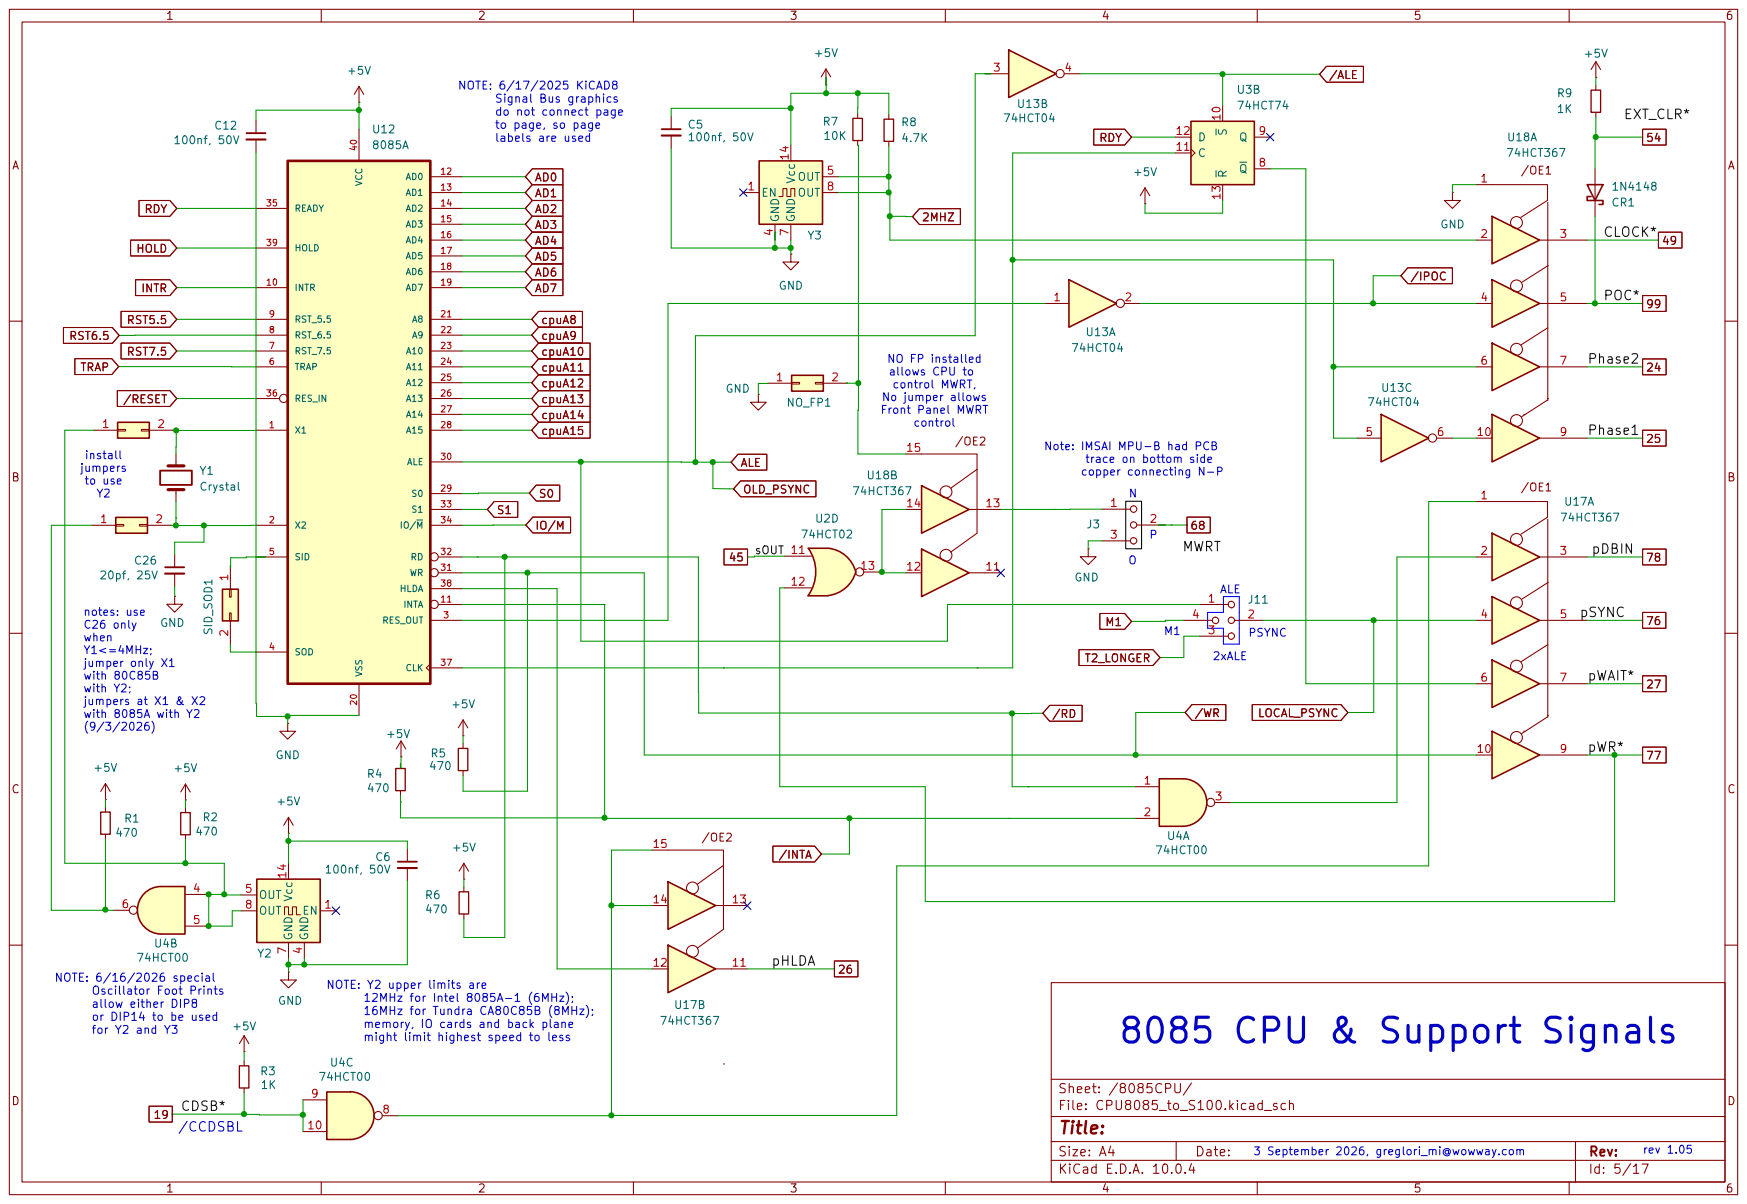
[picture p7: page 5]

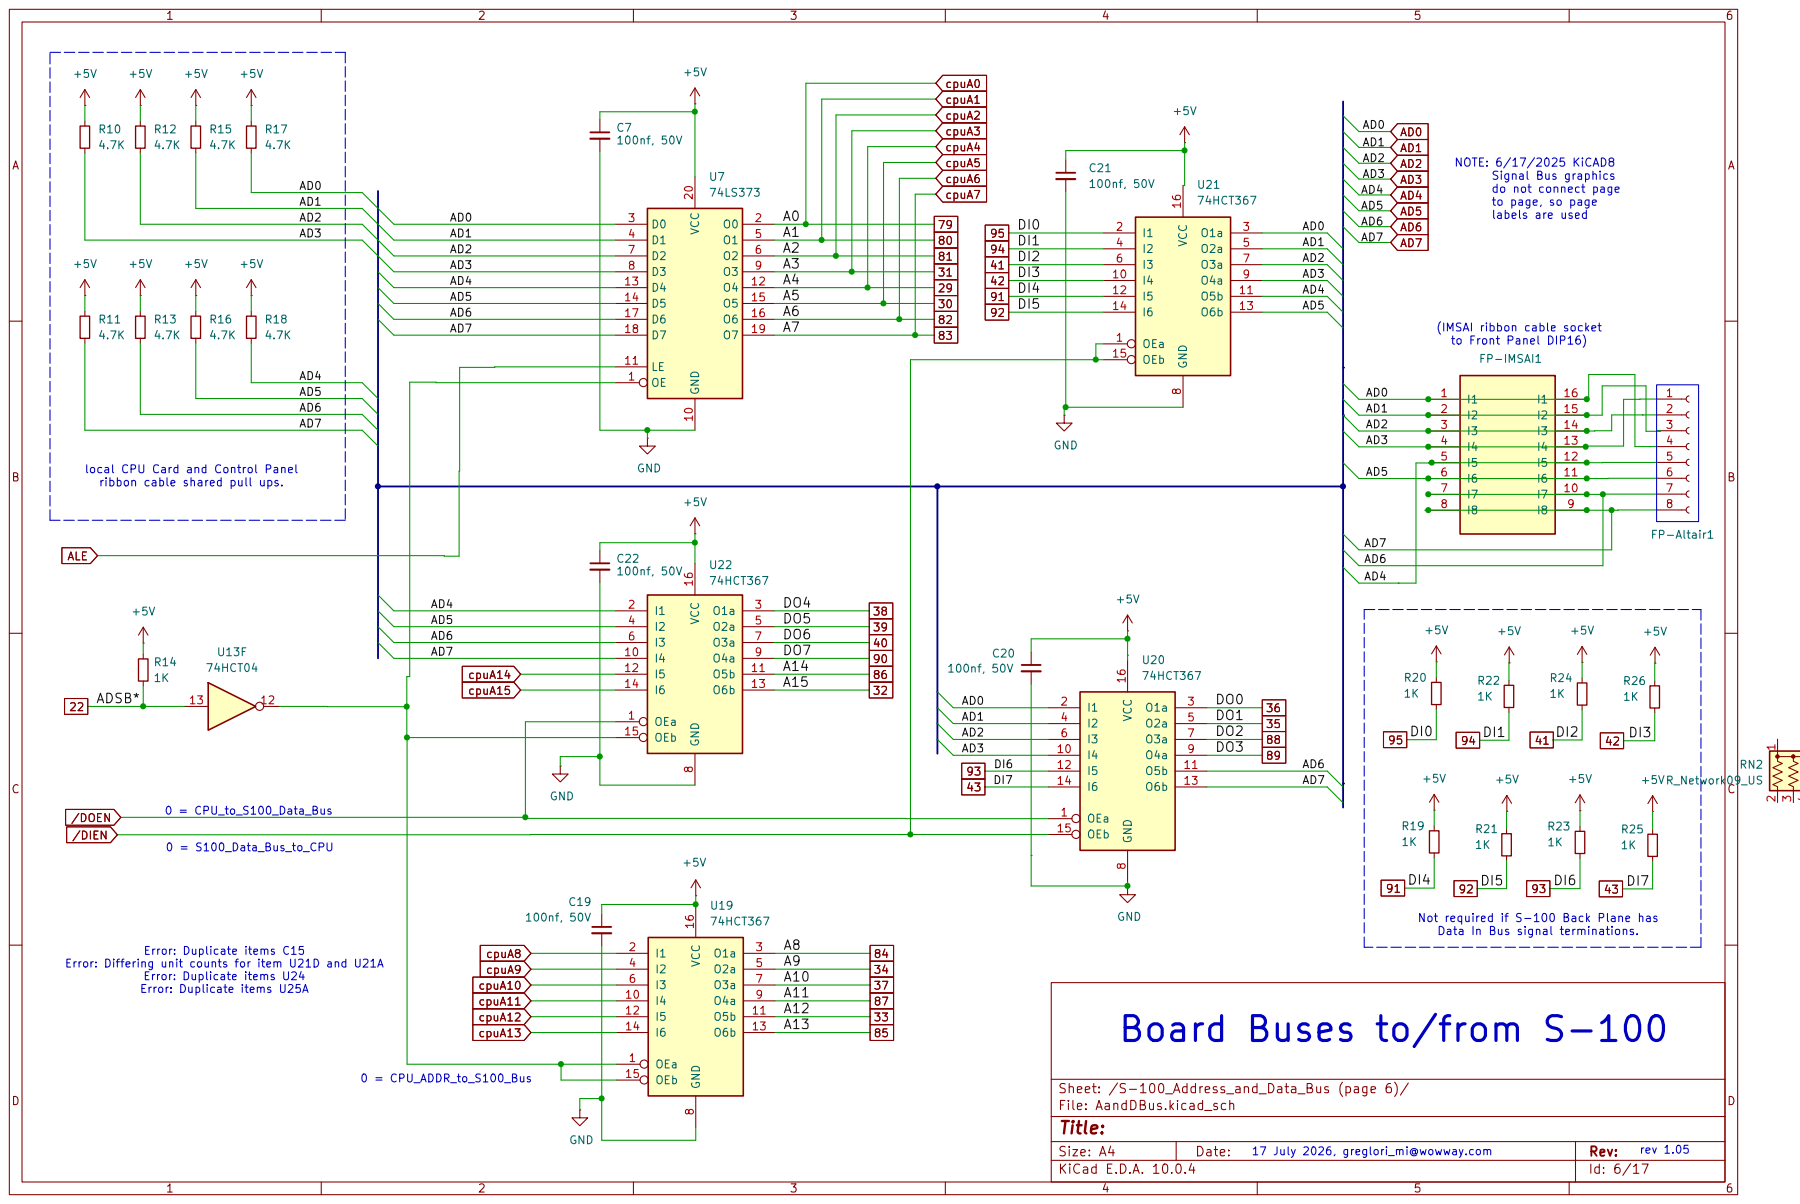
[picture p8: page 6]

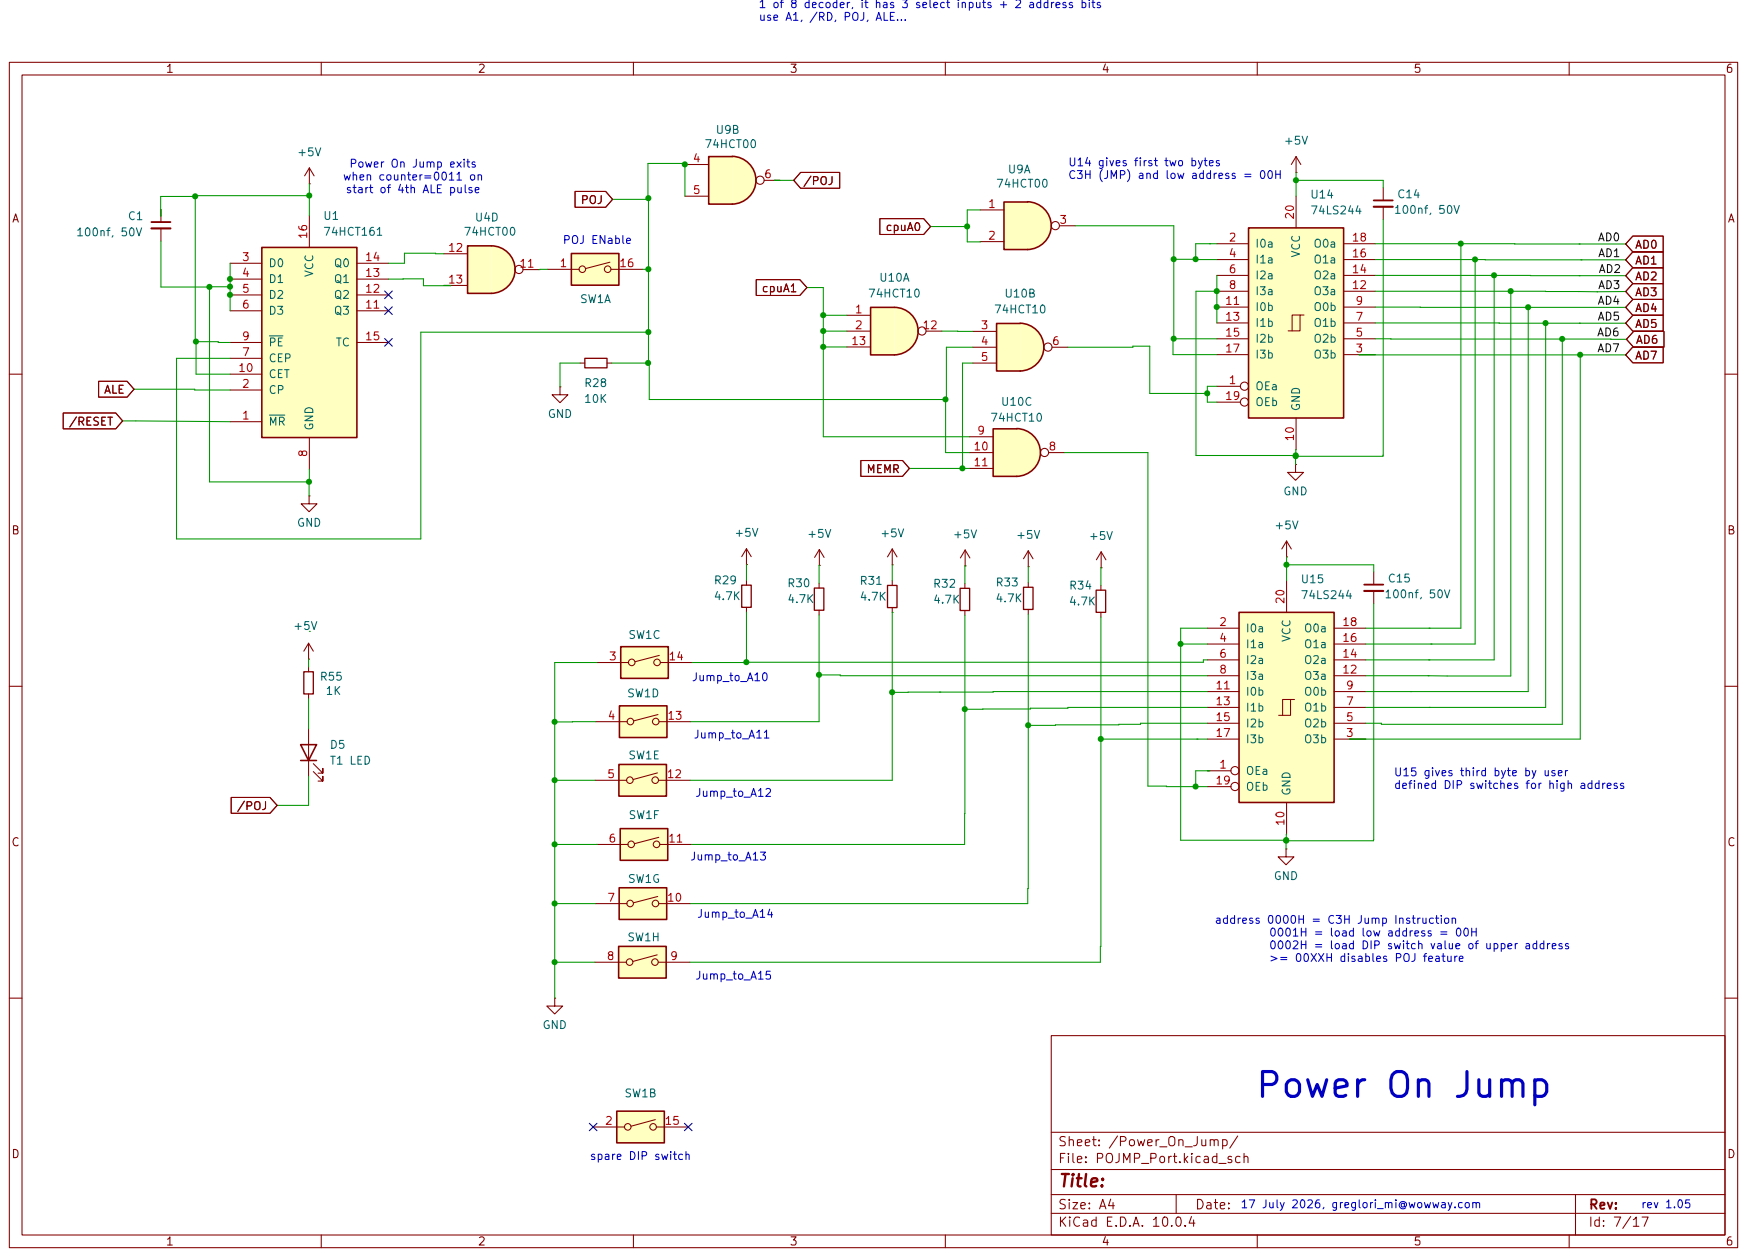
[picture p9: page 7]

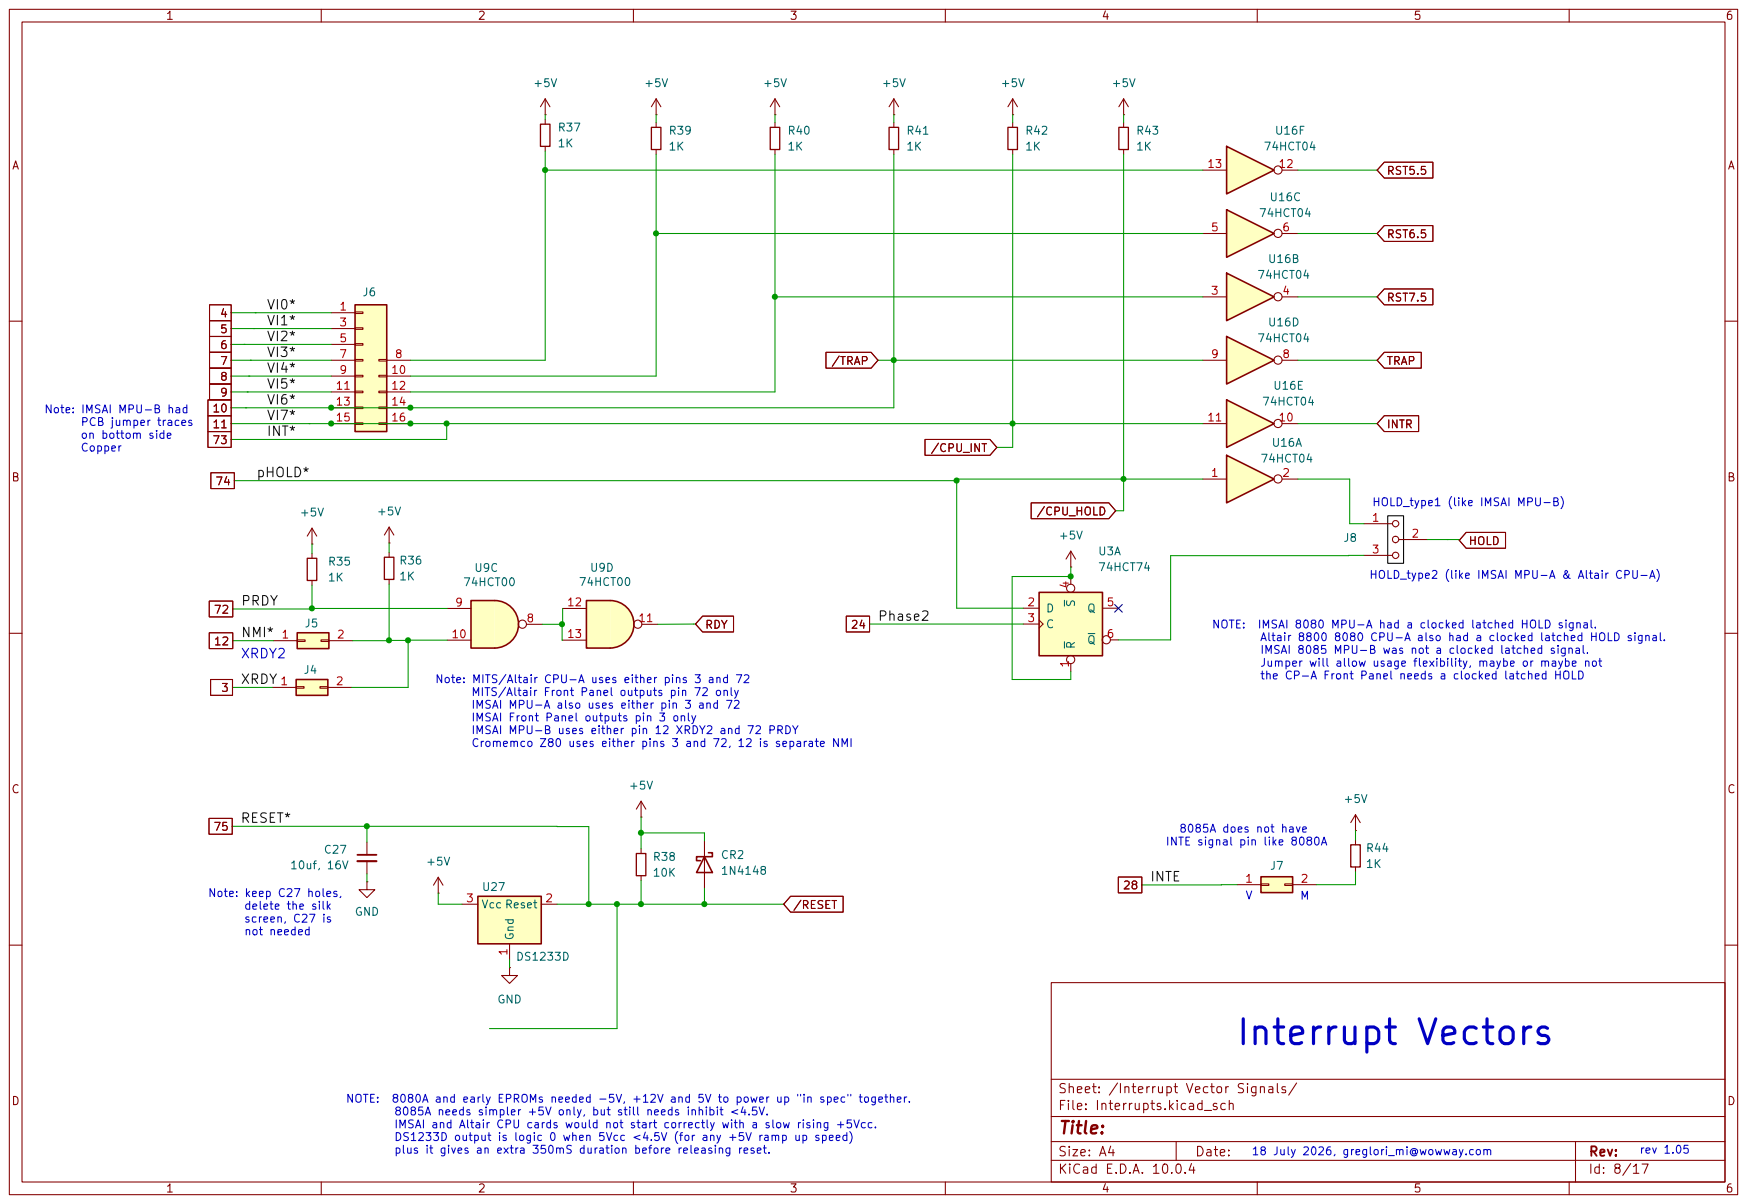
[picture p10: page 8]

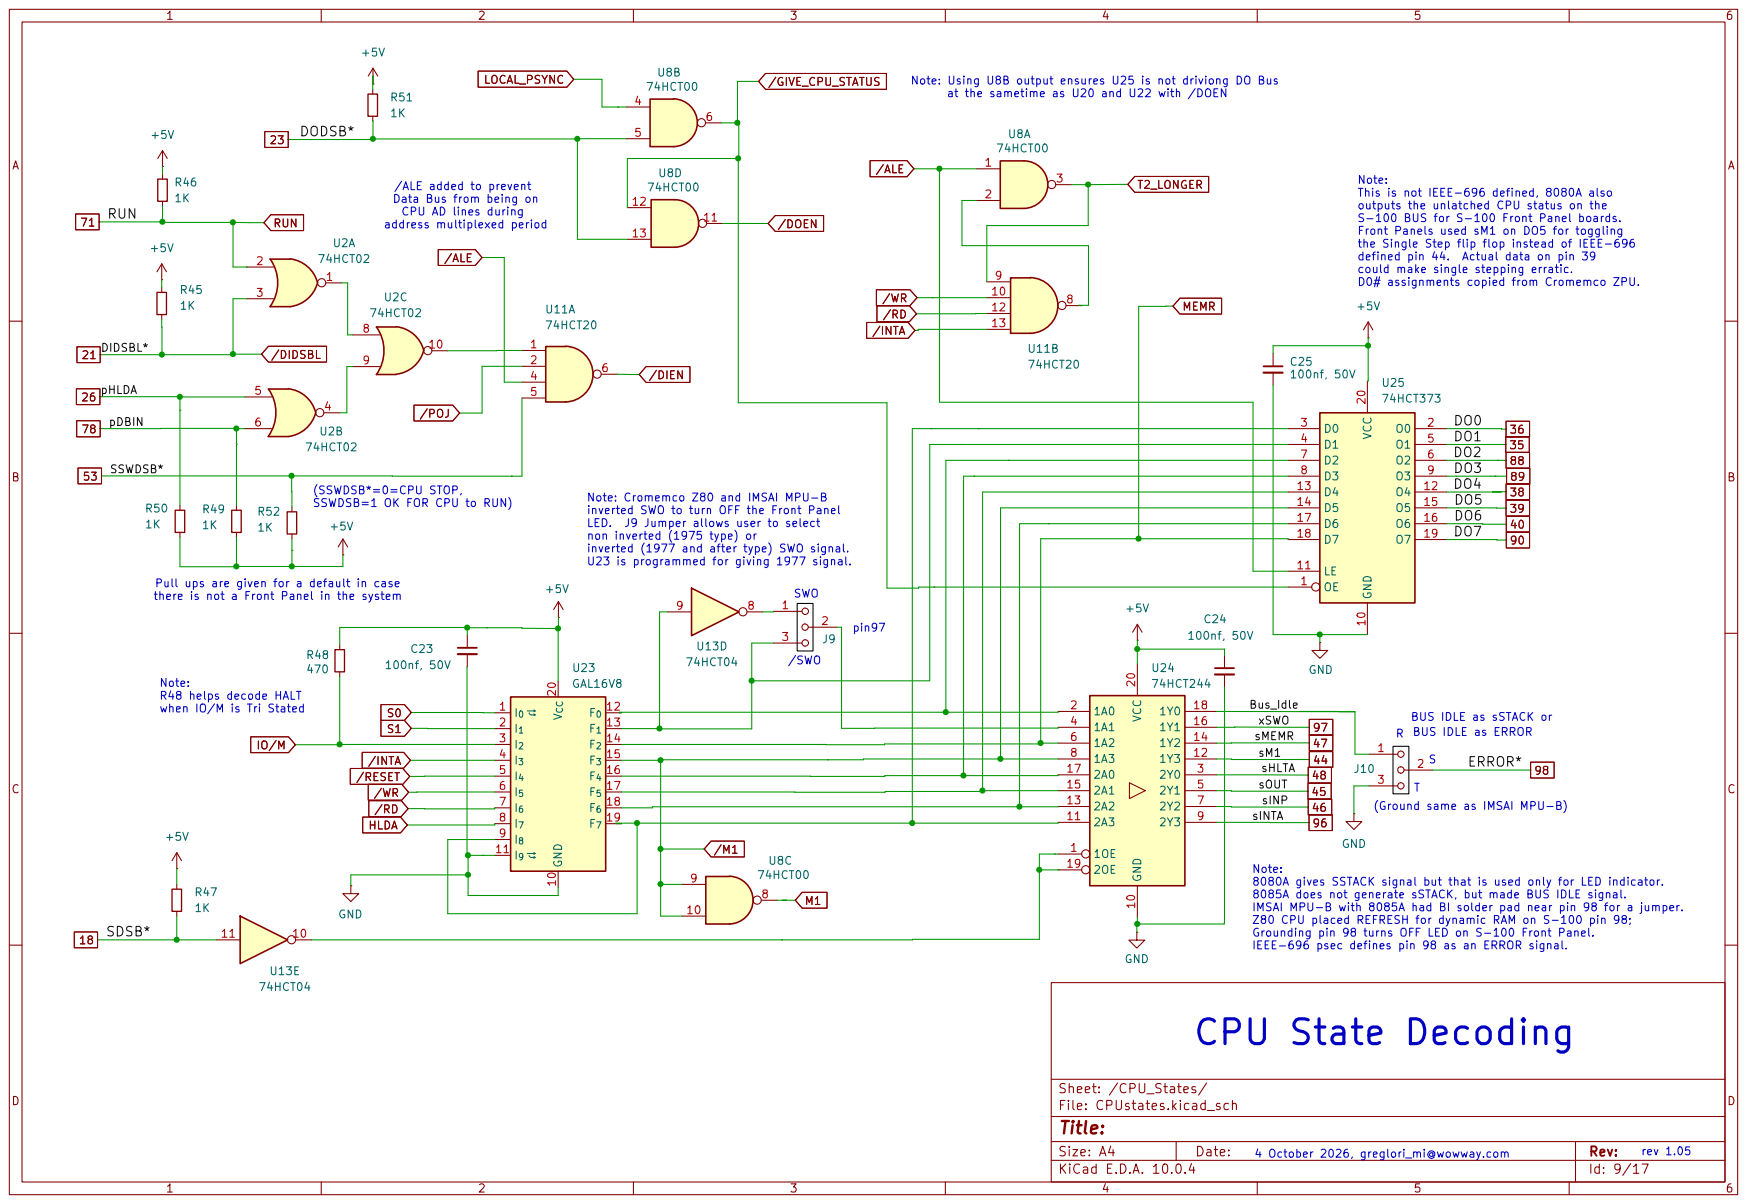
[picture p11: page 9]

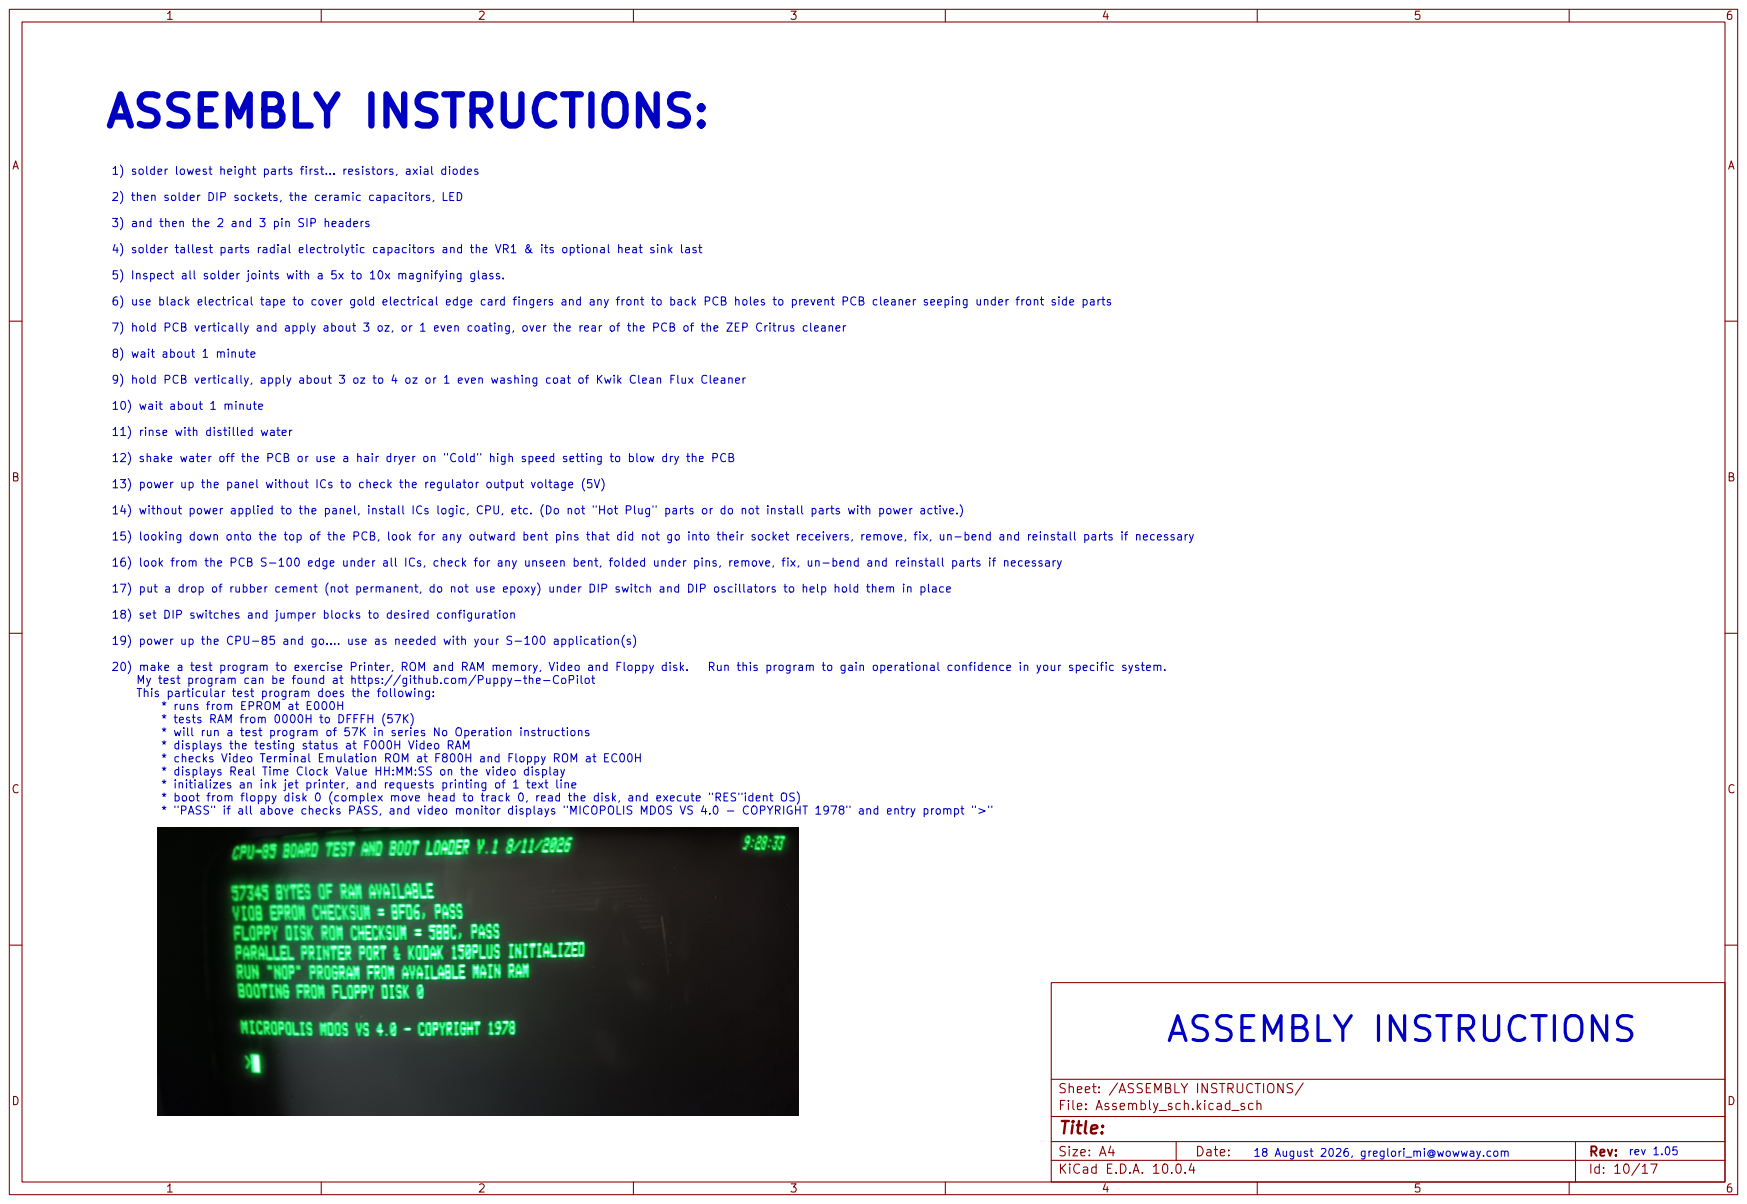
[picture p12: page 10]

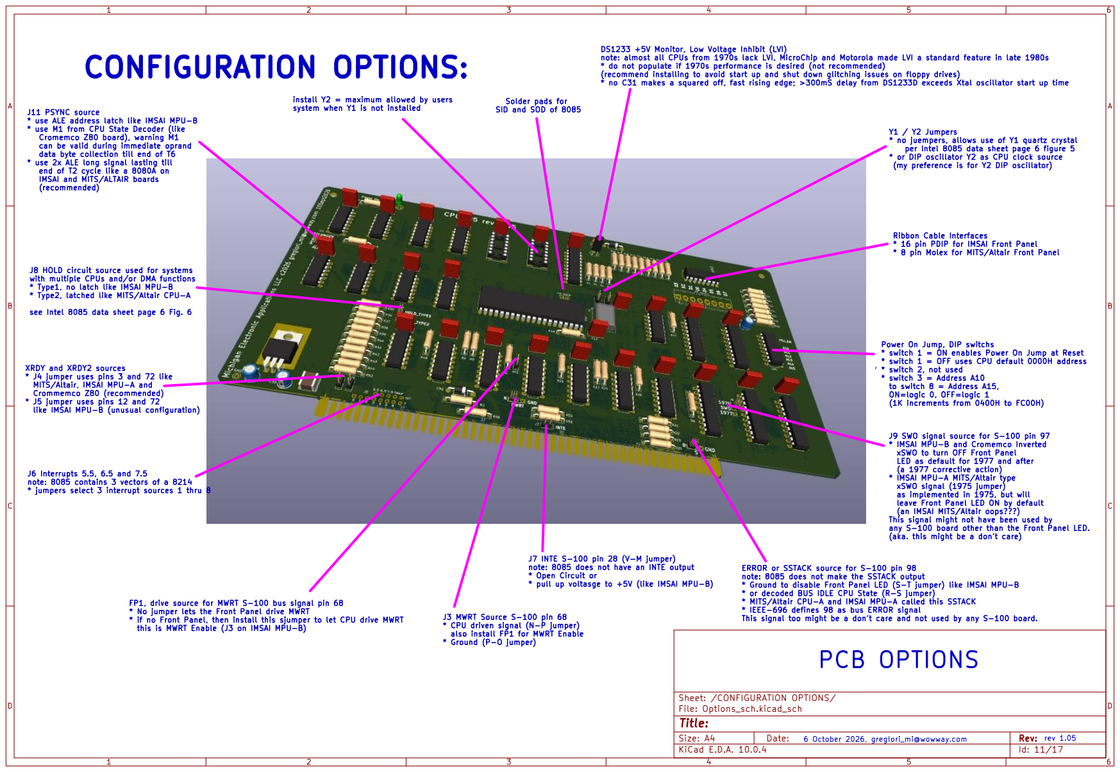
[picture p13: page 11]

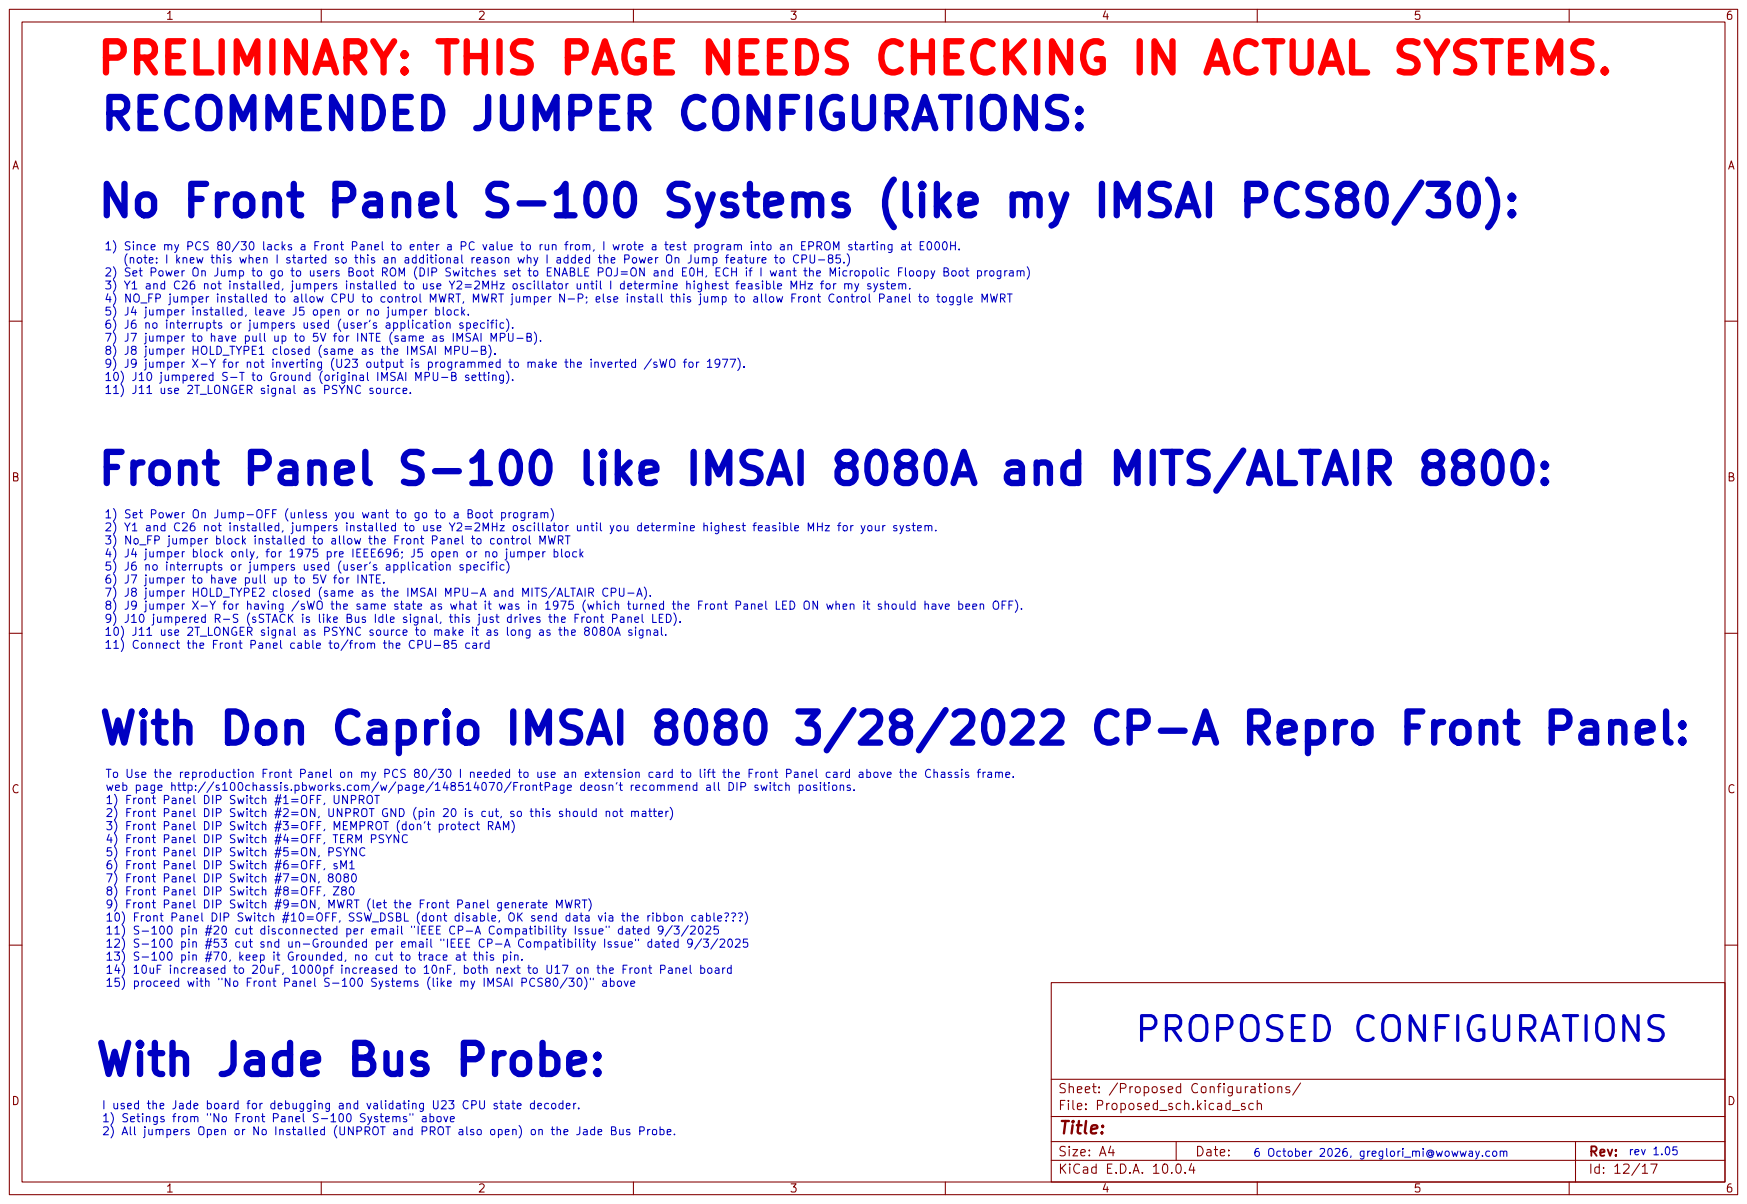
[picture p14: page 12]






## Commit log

2026-08-04 Update validation sample status in README
    Updated the status of the first validation sample to reflect progress.
2026-08-04 CPU-85 Bill of Materials
    [CPU85_rev1dot04_BOM_18July2026.xls]
2026-08-07 Delete CPU85_rev1dot04_BOM_18July2026.xls
    updated to newer file
    [CPU85_rev1dot04_BOM_18July2026.xls]
2026-08-08 Delete CPU85_rev1dot04_BOM_6Aug2026.xls
    updated today
    [CPU85_rev1dot04_BOM_6Aug2026.xls]
2026-08-17 Add files via upload
    updated BOM
    [CPU85_rev1dot04_BOM_16Aug2026.xls]
2026-09-30 Add files via upload
    updates from September 2026
    [CPU85_rev1dot05_BOM_28Sept2026.xls]
